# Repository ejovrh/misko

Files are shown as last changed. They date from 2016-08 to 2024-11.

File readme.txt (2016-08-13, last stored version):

miško - the self sufficient gps tracker

1. ABOUT
	TODO
	Once upon a time, the need was to be able to geotag pictures I take with my camera while enjoying outdor activities.
	I order to satisfy this need I purchased the so-popular GPS recievers which run on a single AA battery (and have a bluetooth 
	transmitter) and a bluetooth module that attaches to the camera.
	This has proven to be futile because of battery runtime, storage capacity and so on.
	
	The original GPS tracker started its life as a (curiosity) kit from adafruit out of the need to have a 
		GPS tracker for my outdoor adventures which meets the following criteria:
			- does not run on AA batteries
			- has a sufficiently long standalone runtime
			- provides logging funcionality 
			- provides a bluetooth interface so that I can geotag pictures I take
			- can be charged by various means
			
		There are professional GPS devices which can (partly) do the job but they do cost a bit more than petty cash 
		and im not that rich.
		
		In my Searches on the Internet I did not find a product which has all the above features implemented; i did find, however, 
		a kit which provides logging of GPS data to a SD card.
		
		Now, GPS modules -usually- use the NMEA protocol; NMEA -usually- utilizes RS232 as a transport [TTL is another choice].
		RS232 is used by the kit's logic to parse incoming data and (RS232) can be easily fed into a bluetooth module.
		The camera has a bluetooth module - it is naturaly to experiment and see if this kit can be tailored to my needs.
		
		This repository attepts two things:
			- document the efforts of producing a suitable GPS tracker (its my university thesis, after all....)
			- produce a GPS tracker which has the following main features:
				- records GPS data and writes it to storage media (after vacations, google earth and the visited route are a nice thing to have)
				- provides NMEA sentences to the camera via bluetooth to geotag pictues
				- has sufficiently long runtime
				- comes in a waterproof box, is to some extent shockproof, dustproof and can handle some abuse
				- can be supplied with electricity on the road (by means of bicycle dynamo, solar cells, mains outlet)
				- can, if need be, charge my mobile phone
				- has certain functionalities user-configurable via buttons
				- displays certain tokens of inromation via LCD
				
				bonus features:
					- uploads the route at definable intervals to some server via GSM ( Big Mother is watching... )
					- log other interesting data to storage
					- get rid of the awful Arduino IDE and use a real one - AVR studio, for example
					
		That's the rough story of it...

2. SOFTWARE USED
	Arduino IED - an open source IDE for the atmel chips
		https://www.arduino.cc/en/Main/Donate
		note: in windows 7 you may need to manually opdate drivers 
		reason: it may be that the ATmega2560 board is not recognized with the stock OS driver
				the appropriate driver is located in the arduino installation
				go to device manager, find the faulty USB device, manually update driver from the arduino install path
		
	Arduino core libraries
		https://www.arduino.cc/en/Reference/Libraries
		SoftwareSerial, SD, EEPROM for interfacing various devices offered by the atmega2560

	Fritzing - an open source entry-level PCB design tool
		http://fritzing.org/download/?donation=0
		
	MS Visio 
		used for some diagrams

	AutoCAD 
		used for enclosure diagrams, stl files for 3D printing
		
	tortoise git
		https://tortoisegit.org/
		a frontend for GIT, utilizing the github repository
		"git for windows" is needed as the backend for communication/functionality of hte github repository
		
	git for windows
		https://git-for-windows.github.io/
		the backed for git-for-windows
			
	u8glib
		https://github.com/olikraus/u8glib
		a display driver library for all kinds of displays
		
	m2tklib
		https://github.com/olikraus/m2tklib
		an graphics library for all kinds of display devices

3. FILES / FOLDERS
	datasheets: contains datasheets, user guides for components
	misko-prototype: prototype firmware code which provides GPS tracker functionality
	battery holder.dwg: AutoCAD drawing of the battery holder
	LiIon battery.dwg: crude AutoCAD model of one battery, contains lateral dimensions
	prototype gps tracker - high level diagram.vsd: MSVisio diagram showing a high level overview of the hardware setup
	readme.txt: this file
	universal hardcase 50.dwg: crude AutoCAD drawing of the enclosure 
	
4. DEVICES
	4.1 misko-prototype
		The original hardware, in kit-form, lived its life in an Iphone3 box and has seen parts of the world on my bicycle.
		It worked well for its humble beginnings, but not well enough.
		Now it lives its life on a piece of cardboard, connected to breadboards, does not leave the home and serves as a 
		development instance.
		
		The role of this environment is development (hardware and software).
		
	4.2 misko-qa
		TODO
		The QA hardware/instance will be based on the prototype's schematics - PCB's tailored to fit into the enclosure and to 
		support features listed.
		Provided the PCB's are good (free of hardware bugs), it will serve as a software (and partially hardware) QA instance for the 
		jump of changes from development to production hardware.
	
	4.2 misko-prod
		TODO
		The production hardware/instance will be used in a live environment (real travels with rain and wind and everything).
		
		Changes on this environment will go through a controlled change cycle - first dev, then QA, then prod.
		
		Developers who know me from my work environment are entitled to my opinion and may now laugh as much as they want.
		
5. HARDWARE USED

	- Arduino Mega2560
		http://hr.rsdelivers.com/product/arduino/a000067/arduino-mega/7154084.aspx

	- Analog Devices TMP36FSZ Temperature Sensor 8-Pin SOIC
		http://hr.rsdelivers.com/product/analog-devices/tmp36fsz/analog-devices-tmp36fsz-temperature-sensor-8-pin-soic-40-125-c/0412973.aspx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
	
	- International Rectifier IRLZ44NSTRLPBF N-channel MOSFET Transistor, 47 A, 55 V, 3-Pin D2PAK
		http://hr.rsdelivers.com/product/international-rectifier/irlz44nstrlpbf/international-rectifier-irlz44nstrlpbf-n-channel-mosfet-transistor-47-a-55-v-3-pin-d2pak/8303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
		
	- Texas Instruments SN74AHC14D, Hex Schmitt Trigger Inverter, 8mA, 2 → 5.5 V, 14-Pin SOIC

		http://hr.rsdelivers.com/product/texas-instruments/sn74ahc14d/texas-instruments-sn74ahc14d-hex-schmitt-trigger-inverter-8ma-2-55-v-14-pin-soic/0526616.aspx
		
	- Atmel 2560
	
		http://hr.rsdelivers.com/catalogue/search.aspx?query=atmega2560&Family=9511#PI-1|viewtype-0|A-236854|
	
	- Microchip 23K256-I/SN SRAM Memory, 256kbit, 2.7 → 3.6 V, 25ns 8-Pin SOIC
	
		http://hr.rsdelivers.com/product/microchip/23k256-i-sn/microchip-23k256-i-sn-sram-memory-256kbit-27-36-v-25ns-8-pin-soic/6668148.aspx
		
	-

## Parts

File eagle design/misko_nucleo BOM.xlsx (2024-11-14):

Qty | Value | Device | Package | Parts | Description
1 | 1.5F 4F | EECS5R5H155 MAL219691104E3 | TH | GPS:SC:C24 | supercap 1.5F or 4F | 504-HS0814-3R8106-R 594-MAL219691104E3 | https://eu.mouser.com/ProductDetail/504-HS0814-3R8106-R https://eu.mouser.com/ProductDetail/594-MAL219691104E3
1 | 100k | R-EU_R0402 | R0402 | GPS:SV:R18 | RESISTOR, European symbol | 667-ERA-2AEB104X | https://eu.mouser.com/ProductDetail/Panasonic/ERA-2AEB104X?qs=YFwoyZoVY0jijibKYIWHHg%3D%3D
1 | 1u / 16V | C-EUC0402 | C0402 | GPS:G:C2 | CAPACITOR, European symbol | 963-TMK105BJ105MV-F | https://hr.mouser.com/ProductDetail/963-TMK105BJ105MV-F
1 | 33R | R-EU_R1206 | R1206 | GPS:SC:R1 | RESISTOR, European symbol | 754-HRG3216Q33R0DT1 | https://eu.mouser.com/ProductDetail/Susumu/HRG3216Q-33R0-D-T1?qs=Pccw3SRxl2QVimWmCTvNQQ%3D%3D
1 | 47309-2651 | MICROSD_SPI_MODE | MICRO_SD_CONNECTOR | IC1101 | MOLEX - 49225-0821 - CONNECTEUR MICRO SD PUSH/PUSH REVFabricant: MOLEXCode commande Farnell: 1366700Référence fabricant: 49225-0821 | 538-47309-2651 | https://eu.mouser.com/ProductDetail/Molex/47309-2651?qs=%252Bi0aAQIdfgCnu2Vhp4wRvw%3D%3D
1 | 47nF / 10V | C-EUC0402 | C0402 | C401 | CAPACITOR, European symbol | 81-GRT155R71H473KE1D | https://eu.mouser.com/ProductDetail/81-GRT155R71H473KE1D
1 | 55R | R-EU_R0402 | R0402 | R1701 | RESISTOR, European symbol | 667-ERA-2AEB54R9X | https://eu.mouser.com/ProductDetail/Panasonic/ERA-2AEB54R9X?qs=nuXzIS8loXFivPgOLhNE3A%3D%3D
1 | 65R | R-EU_R0402 | R0402 | R1702 | RESISTOR, European symbol | 667-ERA-2AEB64R9X | https://eu.mouser.com/ProductDetail/Panasonic/ERA-2AEB64R9X?qs=nuXzIS8loXHLmutffSowkg%3D%3D
1 | 74HCT1G32GW | 74HCT1G32GW-DC | SOT353/5 | IC1302 | Two Input OR gate | 771-HCT1G32GW125 | https://eu.mouser.com/ProductDetail/Nexperia/74HCT1G32GW125?qs=P62ublwmbi9uVFb7WoNXSA%3D%3D
1 | ADXL345 | ADXL345 | LGA14 | IC1301 | 3-Axis, ±2 g/±4 g/±8 g/±16 g Digital Accelerometer | 584-ADXL345BCCZ | https://eu.mouser.com/ProductDetail/584-ADXL345BCCZ
1 | FM25W256 | FM25W256-SOIC | SOIC08 | IC1201 | FeRAM Module | 877-FM25W256-GTR | https://eu.mouser.com/ProductDetail/Infineon-Technologies/FM25W256-GTR?qs=pA5MXup5wxGoDW6i2AFyWw%3D%3D
1 | LTC4425EDD#PBF | LTC4425DFN-12 | DFN-12 | GPS:SC:IC2 | The ISL85003 and ISL85003A are synchronous buck regulators with integrated high-side and low-side FET’s. The regulator can operate from an input voltage range of 4.5V to 18V while delivering a very efficient continuous 3A current. | 584-LTC4425EDD#PBF | https://eu.mouser.com/ProductDetail/584-LTC4425EDD%23PBF
1 | ORG1510-MK4 | ORG1510-MK4 | SMD | GPS:G:IC1
1 | TCAN334 | CAN33X | SOT23-8 | IC401 |  | 595-TCAN334GDCNT | https://eu.mouser.com/ProductDetail/595-TCAN334GDCNT
1 | TPS3808G33DBVT | TPS3808WSON6 | WSON-6 | GPS:SV:IC2 | Low Quiescent Current, Programmable-Delay Supervisory Circuit | 595-TPS3808G33DRVT | https://eu.mouser.com/ProductDetail/595-TPS3808G33DRVT
1 | WP710A10LZGCK | LEDSQR2X5 | LED2X5 | LED1703 | LED | 604-WP710A10LZGCK | https://eu.mouser.com/ProductDetail/604-WP710A10LZGCK
1 | WP710A10SEC | LEDSQR2X5 | LED2X5 | LED1701 | LED | 604-WP710A10SEC | https://eu.mouser.com/ProductDetail/604-WP710A10SEC
1 | WP710A10SECK/J3 | LEDSQR2X5 | LED2X5 | LED1704 | LED | 604-WP710A10SECKJ3 | https://eu.mouser.com/ProductDetail/604-WP710A10SECKJ3
1 | misko | NUCLEO-H503RB-B02 | NUCLEO-H503RB-B02 | BRD1 | Check availability | 511-NUCLEO-H503RB | https://eu.mouser.com/ProductDetail/STMicroelectronics/NUCLEO-H503RB?qs=Jm2GQyTW%2Fbg7Js7%2FR9xxmw%3D%3D
2 | 100u / 16V | C-EUC1210 | C1210 | GPS:SC:C1, GPS:SC:C34 | CAPACITOR, European symbol | 581-1210YD107MAT2A | https://eu.mouser.com/ProductDetail/KYOCERA-AVX/1210YD107MAT2A?qs=dTuOkNN7mNJArH0RUYK6ig%3D%3D
2 | 10k | R-EU_R0402 | R0402 | GPS:SC:R2, GPS:SC:R14 | RESISTOR, European symbol | 667-ERA-2AEB103X | https://hr.mouser.com/ProductDetail/667-ERA-2AEB103X
2 | 150k | R-EU_R0402 | R0402 | GPS:SC:R40, GPS:SC:R41 | RESISTOR, European symbol | 603-RT0402FRE07150KL | https://hr.mouser.com/ProductDetail/603-RT0402FRE07150KL
2 | 33p / 16V | C-EUC0402 | C0402 | GPS:G:C22, GPS:G:C31 | CAPACITOR, European symbol | 80-C0402C330J4RAUTO | https://eu.mouser.com/ProductDetail/KEMET/C0402C330J4RACAUTO?qs=yQ9FZw9SO3y3aZ9BD6Y8Rw%3D%3D
2 | 60 | R-EU_R0805 | R0805 | R401, R405 | RESISTOR, European symbol | 667-ERA-6AEB60R4V | https://eu.mouser.com/ProductDetail/667-ERA-6AEB60R4V
2 | TL3305CF160QG | TL3305-844809 | SMD | SW1401, SW1402 |  | 612-TL3305CF160QG | https://eu.mouser.com/ProductDetail/?qs=UrFqKgNWc7QzvF9YzOUMwg%3D%3D
3 | 33R | R-EU_R0402 | R0402 | GPS:G:R1, GPS:G:R2, R1703 | RESISTOR, European symbol | 279-CPF0402B33RE1 | https://eu.mouser.com/ProductDetail/TE-Connectivity-Holsworthy/CPF0402B33RE1?qs=iJVBkmKXgrn7rsFDnZJSMA%3D%3D
4 | SQ2310ES-T1_BE3 | BSS123 | SOT23 | GPS:SC:Q4, Q1701, Q1702, Q1703 | N-CHANNEL MOS FET | 78-SQ2310ES-T1_BE3 | https://eu.mouser.com/ProductDetail/Vishay-Siliconix/SQ2310ES-T1_BE3?qs=TiOZkKH1s2S1D6d8keGc4Q%3D%3D
8 | 0.1u / 16V | C-EUC0402 | C0402 | C405, C1131, C1201, C1304, GPS:G:C1, GPS:SC:C38, GPS:SV:C1, GPS:SV:C2 | CAPACITOR, European symbol | 80-C0402C104J4RECLR | https://hr.mouser.com/ProductDetail/80-C0402C104J4RECLR

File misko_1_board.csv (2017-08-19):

Part | Value | Device | Package | Description | DESCRIPTION | MF | MPN | OC_FARNELL | OC_NEWARK | PACKAGE | SUPPLIER | TP_SIGNAL_NAME
C1 | 18pF | C-EUC0805 | C0805 | CAPACITOR, European symbol
C2 | 1µF | C-EUC0805 | C0805 | CAPACITOR, European symbol
C3 | 0.1µF | C-EUC0805 | C0805 | CAPACITOR, European symbol
C4 | 0.1µF | C-EUC0805 | C0805 | CAPACITOR, European symbol
C5 | 10µF | C-EUC0805 | C0805 | CAPACITOR, European symbol
C6 | 4.7µF | C-EUC0805 | C0805 | CAPACITOR, European symbol
C7 | 18pF | C-EUC0805 | C0805 | CAPACITOR, European symbol
C8 | 15pF | C-EUC0805 | C0805 | CAPACITOR, European symbol
C9 | 1µF | C-EUC0805 | C0805 | CAPACITOR, European symbol
C10 | 1µF | C-EUC0805 | C0805 | CAPACITOR, European symbol
C11 | 10µF | C-EUC0805 | C0805 | CAPACITOR, European symbol
C12 | 15pF | C-EUC0805 | C0805 | CAPACITOR, European symbol
C13 | 0.1µF | C-EUC0805 | C0805 | CAPACITOR, European symbol
C14 | 1µF | C-EUC0805 | C0805 | CAPACITOR, European symbol
C15 | 1µF | C-EUC0805 | C0805 | CAPACITOR, European symbol
C16 | 10µF | C-EUC0805 | C0805 | CAPACITOR, European symbol
C17 | 2.2µF / 25V | C-EUC0805 | C0805 | CAPACITOR, European symbol
C18 | 1nF | C-EUC0805 | C0805 | CAPACITOR, European symbol
C19 | 0.1µF | C-EUC0805 | C0805 | CAPACITOR, European symbol
C20 | 0.1µF | C-EUC0805 | C0805 | CAPACITOR, European symbol
C21 | 0.1µF | C-EUC0805 | C0805 | CAPACITOR, European symbol
C22 | 10µF | C-EUC0805 | C0805 | CAPACITOR, European symbol
C23 | 10µF | C-EUC0805 | C0805 | CAPACITOR, European symbol
C24 | 10pF | C-EUC0805 | C0805 | CAPACITOR, European symbol
C25 | 1.5F | EECS5R5H155 | TH
C26 | 33pF | C-EUC0805 | C0805 | CAPACITOR, European symbol
C27 | 1000µF | CPOL-EUE5-10.5 | E5-10,5 | POLARIZED CAPACITOR, European symbol
C28 | 10µF | C-EUC0805 | C0805 | CAPACITOR, European symbol
C29 | 10µF | C-EUC0805 | C0805 | CAPACITOR, European symbol
C30 | 1000µF | CPOL-EUE5-10.5 | E5-10,5 | POLARIZED CAPACITOR, European symbol
C31 | 1000µF | CPOL-EUE5-10.5 | E5-10,5 | POLARIZED CAPACITOR, European symbol
C32 | 0.1µF | C-EUC0805 | C0805 | CAPACITOR, European symbol
C33 | 10µF | C-EUC0805 | C0805 | CAPACITOR, European symbol
C34 | 10µF | C-EUC0805 | C0805 | CAPACITOR, European symbol
C35 | 1000µF | CPOL-EUE5-10.5 | E5-10,5 | POLARIZED CAPACITOR, European symbol
C36 | 0.1µF | C-EUC0805 | C0805 | CAPACITOR, European symbol
C37 | 10µF | C-EUC0805 | C0805 | CAPACITOR, European symbol
C38 | 1000µF | CPOL-EUE5-10.5 | E5-10,5 | POLARIZED CAPACITOR, European symbol
C39 | 100µF | C-EUC0805 | C0805 | CAPACITOR, European symbol
C40 | 100µF | C-EUC0805 | C0805 | CAPACITOR, European symbol
C41 | 0.1µF | C-EUC0805 | C0805 | CAPACITOR, European symbol
C42 | 0.1µF | C-EUC0805 | C0805 | CAPACITOR, European symbol
C43 | 0.1µF | C-EUC0805 | C0805 | CAPACITOR, European symbol
CONN1 | JTAG | JTAG-1.27-10-PIN-HEADER | TH-JTAG
CONN2 | I2C | JP4E | JP4 | JUMPER
CONN3 | LiPo Battery | JST_2PIN-THM-RA | JST-PH-2-THM-RA | JST 2-Pin Connectors of various flavors
CONN4 | USB mini B | MX-67503-1230 | SMT
CONN5 | U.FL-R-SMT 1 | ANTENNASMD | SMD | Antenna
D1 | 1N4148 | 1N4148 | D0805 | DIODE
D2 | BAT60AE6327 | BAT60J | SOD323_ST | Schottky barrier diode
D3 | MMSZ5231B-DIO | DIODE-SOD123 | SOD123 | DIODE
IC1 | ATMEGA1281-16AU | ATMEGA1281-16AU | QFP80P1600X1600X120-64N | Microcontroller | Microcontroller |  | ATMEGA1281-16AU | 1455092 | 58M3721 | QFP-64 | ATMEL
IC2 | MC1525TT | MC1525TT | SOT23 | 2.5V and 4.096V Voltage References |  |  |  | unknown | unknown
IC3 | TMP36GRTZ | TMP36GRTZ-REEL7 | SOT95P280X145-5N | Low Voltage Temperature Sensors |  |  | TMP36GRTZ-REEL7 | 1661084 | 96K2116 | SOT23-5 | Analog Devices
IC4 | TPS63031 | TPS63001DRCR | SMT
IC5 | MCP73871-2AAI/ML | MCP73871-2AAI/ML | QFN50P400X400X100-21N | IC, BATTERY CHARGER, 1A |  |  | MCP73871-2AAI/ML | 1642487 | 54M4955 | QFN-20 | Microchip
IC6 | MAX6818 | MAX6818 | TSSOP20
IC7 | FT230XS | FT230XS | SSOP16 | USB to BASIC UART IC
IC8 | SN74LVC1G3157DBVR - BT switch | SN74LVC1G3157DBVR | SOT95P280X145-6N | SINGLE-POLE, DOUBLE-THROW ANALOG SWITCH |  |  | SN74LVC1G3157DBVR | 1470910 | 32H6364 | SOT-23-6 | Texas Instruments
IC9 | SN74LVC1G3157DBVR - GPS switch | SN74LVC1G3157DBVR | SOT95P280X145-6N | SINGLE-POLE, DOUBLE-THROW ANALOG SWITCH |  |  | SN74LVC1G3157DBVR | 1470910 | 32H6364 | SOT-23-6 | Texas Instruments
IC10 | ORG1510-MK4 | ORG1510-MK4 | PACKAGE
IC11 | TPS3808G33DBVT | TPS3808G33DBVT | SOT95P280X145-6N | Low Quiescent Current, Programmable-Delay Supervisory Circuit |  |  | TPS3808G33DBVT | 1755534 | 21J9211 | SOT-23-6 | Texas Instruments
IC12 | LTC4425 | LTC4425 | MSOP | The ISL85003 and ISL85003A are synchronous buck regulators with integrated high-side and low-side FET’s. The regulator can operate from an input voltage range of 4.5V to 18V while delivering a very efficient continuous 3A current.
IC13 | RN4678_BT_MODULE | RN4678_BT_MODULE | SMT
IC14 | ADXL345 | ADXL345 | LGA14 | 3-Axis, ±2 g/±4 g/±8 g/±16 g Digital Accelerometer
IC15 | 74HCT1G32 | 74HCT1G32GW-DC | SOT353/5 | Two Input OR gate
IC16 | FM25W256-SOIC | FM25W256-SOIC | SOIC08 | FeRAM Module |  |  |  | unknown | unknown
IC17 | MICROSD_SPI_MODE | MICROSD_SPI_MODE | MICRO_SD_CONNECTOR | MOLEX - 49225-0821 - CONNECTEUR MICRO SD PUSH/PUSH REVFabricant: MOLEXCode commande Farnell: 1366700Référence fabricant: 49225-0821
IC18 | FH12-30S-0.5SH | FH12-30S-0.5SH | FH12-30S-0.5SH | 0.5mm Pitch Connectors For FPC/FFC |  |  | FH12-30S-0.5SH(55) | 1324555 | 34M6176
IC19 | DS1394U-33+ | DS1394U-33+ | 10UMAX
IC20 | ATWINC1500-MR210PB | ATWINC1500-MR210PB | SMT
IC21 | 115Q-BCA0 | 115Q-BCA0 | 115Q-BCA0
IC22 | SIM800 | SIM800 | SIM800C
L1 | 33µH | L-US | L0805 | INDUCTOR, American symbol
L2 | DJNR3015-1R5 | DJNR3015-1R5 | FFF
L3 | DJNR6045-100-S | DJNR6045-100-S | DJNR6045-100-S | Shielded Power Inductors
LED1 | yellow | LEDCHIPLED_1206 | CHIPLED_1206 | LED
LED2 | yellow | LEDCHIPLED_1206 | CHIPLED_1206 | LED
LED3 | green | LEDSQR2X5 | LED2X5 | LED
LED4 | red | LEDSQR2X5 | LED2X5 | LED
Q1 | ABM3B | ABM3B | SMT
Q2 | LFXTAL016178R | LFXTAL016178R | SMD
R1 | 47k | R-EU_R0805 | R0805 | RESISTOR, European symbol
R2 | 150k | R-EU_R0805 | R0805 | RESISTOR, European symbol
R3 | 4k7 | R-EU_R0805 | R0805 | RESISTOR, European symbol
R4 | 3k3 | R-EU_R0805 | R0805 | RESISTOR, European symbol
R5 | 3k3 | R-EU_R0805 | R0805 | RESISTOR, European symbol
R6 | 27 | R-EU_R0805 | R0805 | RESISTOR, European symbol
R7 | 150k | R-EU_R0805 | R0805 | RESISTOR, European symbol
R8 | 150k | R-EU_R0805 | R0805 | RESISTOR, European symbol
R9 | 10k | R-EU_R0805 | R0805 | RESISTOR, European symbol
R10 | 27 | R-EU_R0805 | R0805 | RESISTOR, European symbol
R11 | 10k | R-EU_R0805 | R0805 | RESISTOR, European symbol
R12 | 100k | R-EU_R0805 | R0805 | RESISTOR, European symbol
R13 | 270k | R-EU_R0805 | R0805 | RESISTOR, European symbol
R14 | 1k | R-EU_R0805 | R0805 | RESISTOR, European symbol
R15 | 1k | R-EU_R0805 | R0805 | RESISTOR, European symbol
R16 | 47k | R-EU_R0805 | R0805 | RESISTOR, European symbol
R17 | 1k | R-EU_R0805 | R0805 | RESISTOR, European symbol
R18 | 1k | R-EU_R0805 | R0805 | RESISTOR, European symbol
R19 | 10k | R-EU_R0805 | R0805 | RESISTOR, European symbol
R20 | 47k | R-EU_R0805 | R0805 | RESISTOR, European symbol
R21 | 1M | R-EU_R0805 | R0805 | RESISTOR, European symbol
R22 | 1k | R-EU_R0805 | R0805 | RESISTOR, European symbol
R25 | 47k | R-EU_R0805 | R0805 | RESISTOR, European symbol
R26 | 390k | R-EU_R0805 | R0805 | RESISTOR, European symbol
R27 | 10k | R-EU_R0805 | R0805 | RESISTOR, European symbol
R28 | 10k | R-EU_R0805 | R0805 | RESISTOR, European symbol
R29 | 1M | R-EU_R0805 | R0805 | RESISTOR, European symbol
R30 | 1k | R-EU_R0805 | R0805 | RESISTOR, European symbol
R31 | 47k | R-EU_R0805 | R0805 | RESISTOR, European symbol
R32 | 10k | R-EU_R0805 | R0805 | RESISTOR, European symbol
R33 | 1k | R-EU_R0805 | R0805 | RESISTOR, European symbol
R34 | 1k | R-EU_R0805 | R0805 | RESISTOR, European symbol
R35 | 1k | R-EU_R0805 | R0805 | RESISTOR, European symbol
R36 | 10k | R-EU_R0805 | R0805 | RESISTOR, European symbol
R37 | 100k | R-EU_R0805 | R0805 | RESISTOR, European symbol
R38 | 1k | R-EU_R0805 | R0805 | RESISTOR, European symbol
R39 | 270k | R-EU_R0805 | R0805 | RESISTOR, European symbol
R40 | NTC 10k | R-EU_0204/5 | 0204/5 | RESISTOR, European symbol
R41 | 10k | R-EU_R0805 | R0805 | RESISTOR, European symbol
R42 | 10k | R-EU_R0805 | R0805 | RESISTOR, European symbol
R43 | 10k | R-EU_R0805 | R0805 | RESISTOR, European symbol
R44 | 150k | R-EU_R0805 | R0805 | RESISTOR, European symbol
R45 | 150k | R-EU_R0805 | R0805 | RESISTOR, European symbol
R46 | 150k | R-EU_R0805 | R0805 | RESISTOR, European symbol
R47 | 150k | R-EU_R0805 | R0805 | RESISTOR, European symbol
SJ1 | WiFi RST | SJW | SJW | SMD solder JUMPER
SJ2 | GPIO6 | SJW | SJW | SMD solder JUMPER
SJ3 | RESET | SJW | SJW | SMD solder JUMPER
SW1 | RESET | 430152050836 | 430152050836 | 6x6 mm SMD WS-TASV
SW2 | POWER SWITCH | SWS001 | SMS-001 | SMD Dip Switch 1 pol.
SW3 | MICROJOYSTICK | MICROJOYSTICK | MICROJOYSTICK
SW4 | PB6156RSL | PB6156RSL | TH
SW5 | PB6156RSL | PB6156RSL | TH
T1 | BSS84 | BSS84 | SOT23 | P-CHANNEL MOS FET
TP1 | GND | TPPAD1-17Y | P1-17Y | Test pad
TP2 | GND | TPPAD1-17Y | P1-17Y | Test pad
TP3 | GND | TPPAD1-17Y | P1-17Y | Test pad
TP4 | VCC | PTR1TP14R | TP14R | TEST PIN
TP5 | VLiIon Regulated | PTR1TP14R | TP14R | TEST PIN
TP6 | VGPS | PTR1TP14R | TP14R | TEST PIN
TP7 | Analogue Switch CRTL Pin | PTR1TP14R | TP14R | TEST PIN
TP8 | GPS Power CTRL Pin | PTR1B1,27 | B1,27 | TEST PIN
TP9 | SIM800 Power CTRL Pin | PTR1B1,27 | B1,27 | TEST PIN
TP10 | Bluetooth Wakeup Pin | PTR1TP14R | TP14R | TEST PIN
TP11 | Bluetooth Wakeup Pin | PTR1TP14R | TP14R | TEST PIN

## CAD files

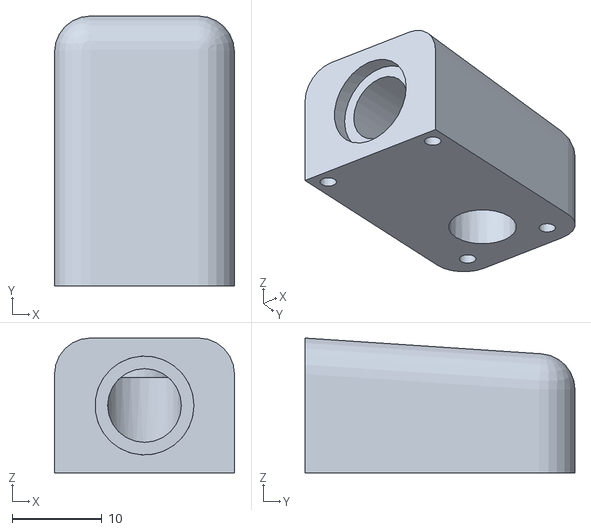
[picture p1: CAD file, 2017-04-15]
universal hardcase 75 - external.stl
20.0 x 30.0 x 15.0

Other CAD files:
universal hardcase 75.dwg
universal hardcase 75 - external.dwg

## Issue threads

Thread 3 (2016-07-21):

document existing prototype

ejovrh, 2016-07-21:
draw up visio diagrams (or similar) showing a block-diagram like overview of components and features so that sbojanic can understand the apparatus

ejovrh, 2016-07-23:
crude block-level diagram with basic data flows and voltages in visio is done

ejovrh, 2016-08-20:
is closed via a block level diagram in splan7

Closed 2016-08-20.

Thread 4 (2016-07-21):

load up the prototype code into git

ejovrh, 2016-07-21:
upload the prototype code, comment it, list open issues and bugs

ejovrh, 2016-07-23:
done, the whole tree is in github, code is compiling, programming works, board functions "as intended"

Closed 2016-07-23.

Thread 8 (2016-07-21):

draw rough battery autocad model

ejovrh, 2016-07-21:
draw the battery model so that a holder for them can be 3dprinted and inserted into the enclosure

Closed 2016-07-21.

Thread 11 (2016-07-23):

document prototype code

ejovrh, 2016-07-23:

ejovrh, 2016-08-12:
the original prototype code is by now so much changed that it doesn't resemble its original form anymore.
this issue can be closed since most components are documented in the code.

Closed 2016-08-12.

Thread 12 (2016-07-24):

fix bluetooth module power

ejovrh, 2016-07-24:
atm it is supplied via 100% PWM duty cycle on pin 9

implement a mosfet via which an analog? port shall trigger the gate

ejovrh, 2016-07-25:
fixed.
bluetooth module power is not controlled via a mosfet, the gate is controlled by pin 53 - bluetooth_mosfet_gate_pin

Closed 2016-07-25.

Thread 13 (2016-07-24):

bluetooth power - implement switchable power by key press, turns off after some time

ejovrh, 2016-07-24:
implement button press for power toggle.
e.g.:
0-1s - power for 20s
2-3s - power for 40s

double click: toggle power on
double click again: toggle power off

perhaps time setting could be implemented by a default and adjustable by LCD menu item

ejovrh, 2016-07-31:
implemented
the method of operation is not a double click but button hold.

if the BT button is held for 500ms or longer, it will turn the BT device on (or off).
state is kept via flags

the button handling logic is improved so that on press only one event is registered (same goes for release).
the timed power off will not kick in if the device power is toggled via "500ms or longer" button hold.

Closed 2016-07-31.

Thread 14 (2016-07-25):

check pins 50-52 for correct operation

ejovrh, 2016-07-25:
test case:
connect e.g. lcd mosfet gate to 50, put on high, upload, check power status of lcd, retest with low state
power state was not consistent

ejovrh, 2016-07-26:
it pays to read the documentation. said pins are reserved for SPI...

Closed 2016-07-26.

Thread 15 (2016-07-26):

make 5-button keypad

ejovrh, 2016-07-26:
- 5 buttons: left, right, up, down, bluetooth toggle
- use hardware debouncing (I'm too lazy to code it) [schmitt trigger]
- in software, digitalRead() shall be enough to determine pin states
- do the math for it: calculate RC circuit for thesis, perhaps (in parallel to math) record it on a oscilloscope [problem is time resolution!!] to see actual results

one good read is https://www.ikalogic.com/de-bouncing-circuits/
another one is http://www.eng.utah.edu/~cs5780/debouncing.pdf

ejovrh, 2016-07-30:
hardware is made, tested and seems to work.
missing is the math and a osci picture showing it

ejovrh, 2016-08-22:
the osci-analysis is not needed

Closed 2016-08-22.

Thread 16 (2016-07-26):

rewrite SD card logging

ejovrh, 2016-07-26:
the current approach uses FAT and writes with 1Hz frequency to the card.
data written is about 2X80 characters (with current NEMA sentence selection) - the card is literally burned since there are lots of writes to the same blocks.
this leads to heavy and unrecoverable FS corruption and the card can eventually be thrown away.

implement:
- SD card utilization which will mitigate excessive writing to the same blocks
- a buffer which will hold NMEA sentences in flash memory and e.g. once in 5 minutes flush its contents to the SD card
- devise a way to read out SD card data without the need to physically remove it from the device
- enable card space utilization statistics, display them on a LCD

Closed 2016-08-27.

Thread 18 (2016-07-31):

rewrite button handlers

ejovrh, 2016-07-31:
their current state is a disgrace; copy and paste code.

ejovrh, 2016-08-20:
left, right, up and down were removed since these are now handled by the M2tk library.
the bluetooth button was rewritten to make it less(more?) complicated and more(less?) clear.
[ at least it has comments... ]

Closed 2016-08-20.

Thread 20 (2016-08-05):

OLED <-> SD issue

ejovrh, 2016-08-05:
the SD card (SPI) init seems to interfere with the OLED on I2C.
fix the issue either with utilizing a different OLED (one with hardware SPI) or otherwise.

ejovrh, 2016-08-13:
resolved.
the culprits were:
- SD.begin() interfered with SPI OLED setup, disabling SD-begin() enabled the OLED to work
- wrong wiring on at least one occasion of tests with HW SPI wiring
- switching to card.init() enabled card initialization and OLED operation at the same time.

Closed 2016-08-13.

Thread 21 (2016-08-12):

improve menu

ejovrh, 2016-08-12:
at the moment the menu displays the basic data needed for the tracker to function.
there are a few missing items (battery status, temperature, lineup of menu elements).
most of them are hardware-independent and can be implemented at a later date.

Closed 2016-08-28.

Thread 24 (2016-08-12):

implement TP36

ejovrh, 2016-08-12:
a temperature sensor shall be implemented and the temperature shall be displayed.
parse frequency shall be a sane ammount of time - e.g. once in 5 minutes

ejovrh, 2016-08-12:
is implemented and tested.
it seems to work well enough, however changes may be made based upon global variables, timer functions and similar things.

ejovrh, 2016-08-13:
the measured voltage fluctuates a lot.
implement an average measurement

ejovrh, 2016-08-21:
implemented an average measurement over configurable iterations.
iterative runs are executed via a primitive scheduler which runs about once per seconds.

Closed 2016-08-21.

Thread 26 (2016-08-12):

implemend ADXL345 accelerometer

ejovrh, 2016-08-12:
the accelerometer shall put the device in a proper sleep state in order to preserve power when no movement is detected.
for this the ADXL345 can trigger interrupt events which the micro-controller has to be able to respond to (go to sleep and wake up after wards).

ejovrh, 2016-08-15:
basic interrupt events are now registered. sleep and power saving is still todo

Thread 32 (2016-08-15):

adxl345_readByte(DEVID) returns 0 on 1st call, subsequent calls are ok

ejovrh, 2016-08-15:
weird issue: the 1st read returns 0, subsequent reads return proper values

ejovrh, 2016-08-22:
this seems to be a wiring issue on the breadboad.
SPI is running at MHz speeds and i have bad contacts, the breadboard - unpredictable sources of capacitance, inductance and resistance.

Closed 2016-08-22.

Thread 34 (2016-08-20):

implement bt power status

ejovrh, 2016-08-20:
bt constant power on/auto /constant off shall be implemented.

ejovrh, 2016-08-20:
implemented via M2_COMBOFN and a nasty bluetooth button handler.
it event works!

Closed 2016-08-20.

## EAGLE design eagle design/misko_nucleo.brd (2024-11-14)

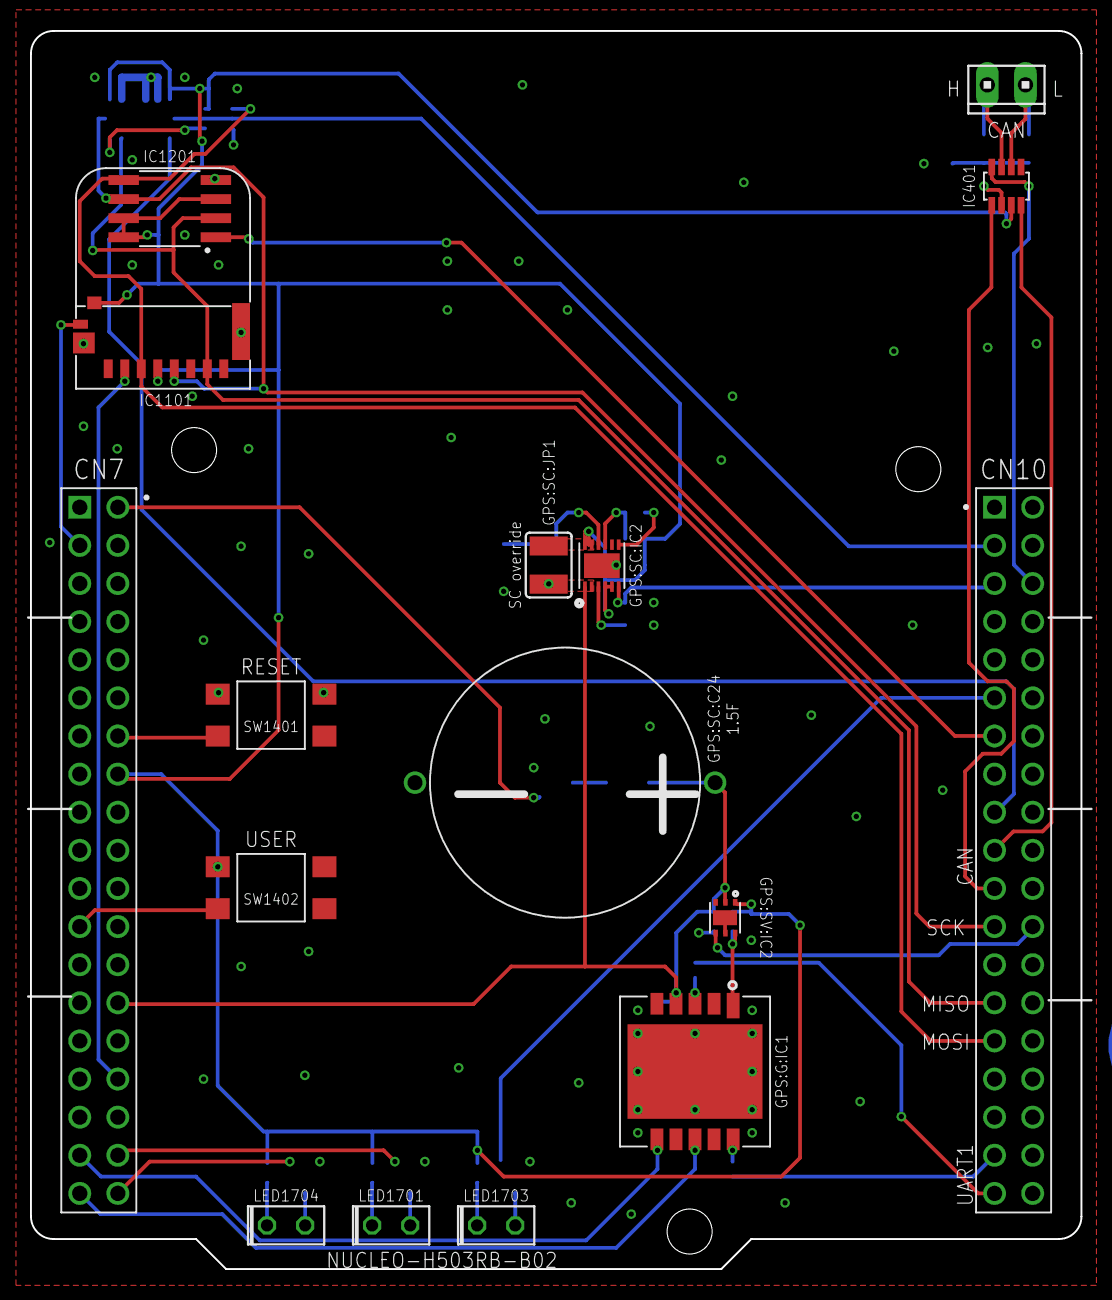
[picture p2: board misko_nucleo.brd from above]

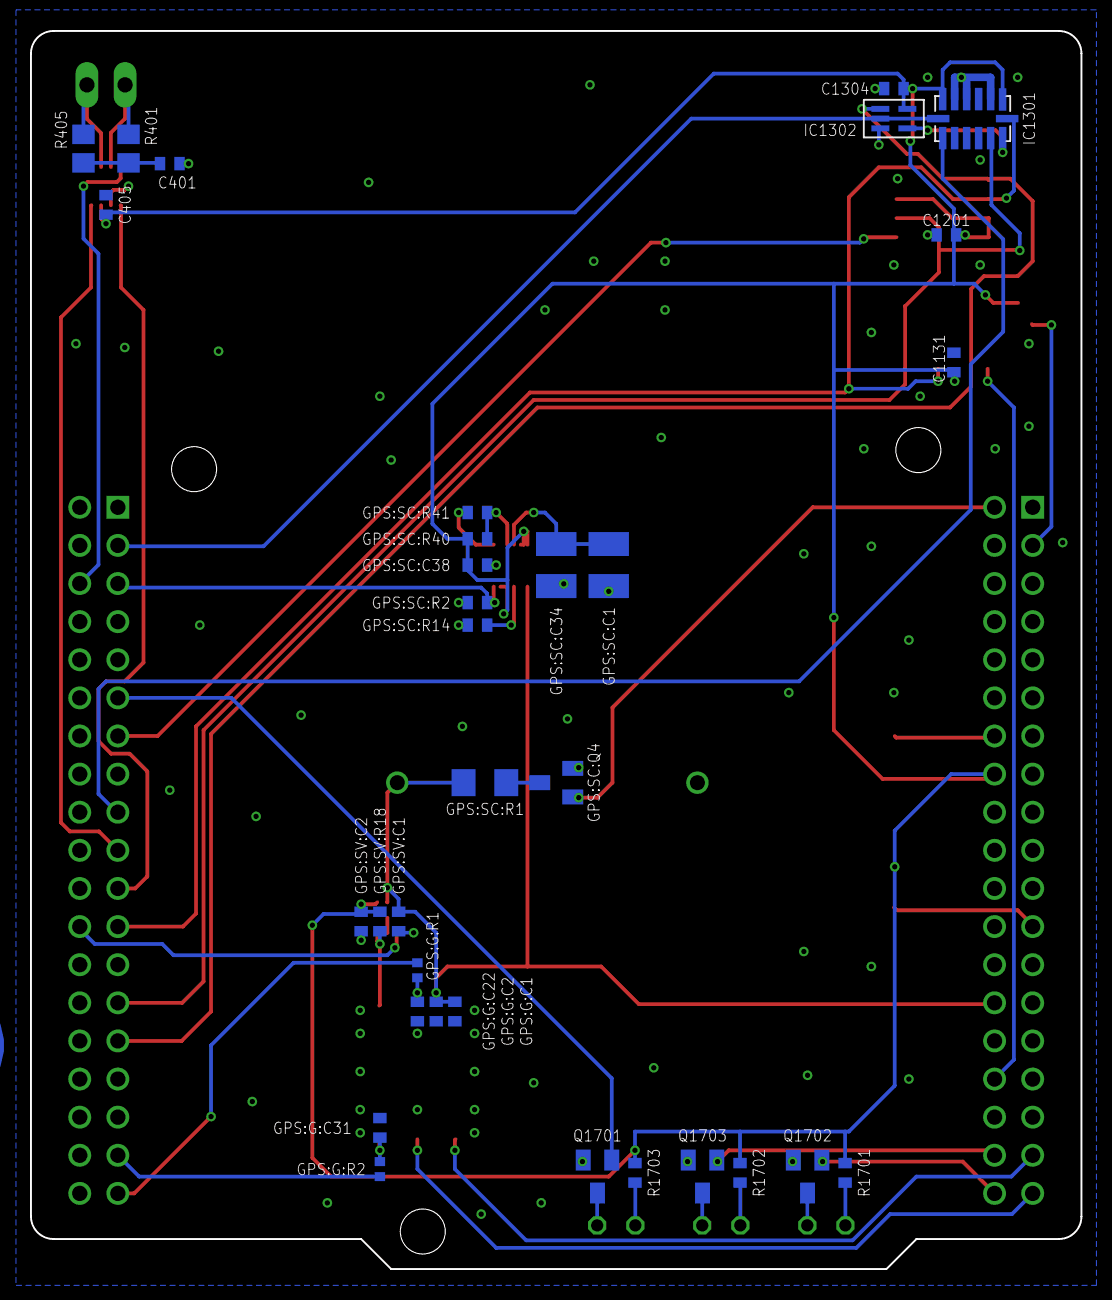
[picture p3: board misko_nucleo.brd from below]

Board: 2 copper layers, 70.0 x 82.5 mm, 48 parts (33 on the bottom side), 44 nets.

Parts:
BRD1: misko; NUCLEO-H503RB-B02
C401: 47nF / 10V; C0402
C405, C1131, C1201, C1304: 0.1u / 16V; C0402
GPS:G:C1: 0.1u / 16V; C0402
GPS:G:C2: 1u / 16V; C0402
GPS:G:C22, GPS:G:C31: 33p / 16V; C0402
GPS:G:IC1: ORG1510-MK4; SMD
GPS:G:R1, GPS:G:R2: 33R; R0402
GPS:SC:C1, GPS:SC:C34: 100u / 16V; C1210
GPS:SC:C24: 1.5F; TH
GPS:SC:C38: 0.1u / 16V; C0402
GPS:SC:IC2: LTC4425EDD#PBF; DFN-12
GPS:SC:JP1: SC override; SJW
GPS:SC:Q4: SQ2310ES-T1_BE3; SOT23
GPS:SC:R1: 33R; R1206
GPS:SC:R2, GPS:SC:R14: 10k; R0402
GPS:SC:R40, GPS:SC:R41: 150k; R0402
GPS:SV:C1, GPS:SV:C2: 0.1u / 16V; C0402
GPS:SV:IC2: TPS3808G33DBVT; WSON-6
GPS:SV:R18: 100k; R0402
IC401: TCAN334; SOT23-8
IC1101: 47309-2651; MICRO_SD_CONNECTOR
IC1201: FM25W256; SOIC08
IC1301: ADXL345; LGA14
IC1302: 74HCT1G32GW; SOT353/5
J1: CAN; 10X02MTA
LED1701: WP710A10SEC; LED2X5
LED1703: WP710A10LZGCK; LED2X5
LED1704: WP710A10SECK/J3; LED2X5
Q1701, Q1702, Q1703: SQ2310ES-T1_BE3; SOT23
R401, R405: 60; R0805
R1701: 55R; R0402
R1702: 65R; R0402
R1703: 33R; R0402
SW1401, SW1402: TL3305CF160QG; SMD

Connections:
3V3: BRD1.CN7_16, C405.1, C1131.1, C1201.1, C1304.1, GPS:SC:C38.1, GPS:SC:IC2.FB, GPS:SC:IC2.SEL, GPS:SC:IC2.VIN1, GPS:SC:IC2.VIN2, GPS:SC:JP1.2, GPS:SC:R40.2, GPS:SV:C2.1, GPS:SV:IC2.VDD, GPS:SV:R18.2, IC401.P$3, IC1101.DET, IC1101.VDD, IC1201.!HOLD!, IC1201.!WP!, IC1201.VCC, IC1301.VCC, IC1301.VDD, IC1302.VCC, R1701.2, R1702.2, R1703.2, SW1402.3, SW1402.4
ADC_VGPS: BRD1.CN7_28, GPS:G:C1.1, GPS:G:C2.1, GPS:G:IC1.4_VCC, GPS:SC:C24.+, GPS:SC:C34.1, GPS:SC:IC2.VOUT1, GPS:SC:IC2.VOUT2, GPS:SC:JP1.1, GPS:SC:R1.2, GPS:SV:C1.1, GPS:SV:IC2.SENSE
ADXL345:ADXL345SDA: IC1301.SDA, IC1302.Y
ADXL345_CS: BRD1.CN10_3, IC1301.!CS!, IC1302.A
ADXL345_INT1: BRD1.CN10_17, IC1301.INT1
CAN_!STBY!: BRD1.CN10_6, IC401.P$8
CAN_H: IC401.P$7, J1.1, R401.2
CAN_INFRA:SPLIT: C401.1, R401.1, R405.2
CAN_L: IC401.P$6, J1.2, R405.1
CAN_RX: BRD1.CN10_19, IC401.P$4
CAN_TX: BRD1.CN10_21, IC401.P$1
GND: BRD1.CN7_8, BRD1.CN7_19, BRD1.CN7_20, BRD1.CN7_22, BRD1.CN10_9, BRD1.CN10_20, BRD1.CN10_32, C401.2, C405.2, C1131.2, C1201.2, C1304.2, GPS:G:C1.2, GPS:G:C2.2, GPS:G:C22.2, GPS:G:C31.2, GPS:G:IC1.5_GND, GPS:G:IC1.GND1, GPS:G:IC1.GND2, GPS:G:IC1.GND4, GPS:G:IC1.GND5, GPS:G:IC1.GND6, GPS:G:IC1.GND7, GPS:G:IC1.GND8, GPS:G:IC1.GND9, GPS:G:IC1.GND10, GPS:G:IC1.GND12, GPS:G:IC1.GND13, GPS:G:IC1.GND14, GPS:G:IC1.GND15, GPS:SC:C1.2, GPS:SC:C24.-, GPS:SC:C38.2, GPS:SC:IC2.GND, GPS:SC:Q4.2, GPS:SC:R2.1, GPS:SC:R14.1, GPS:SV:C1.2, GPS:SV:C2.2, GPS:SV:IC2.GND1, GPS:SV:IC2.GND2, IC401.P$2, IC1101.GND1, IC1101.GND2, IC1101.GND3, IC1201.GND, IC1301.GND1, IC1301.GND2, IC1301.GND3, IC1302.GND, Q1701.2, Q1702.2, Q1703.2, SW1401.3, SW1401.4
GPS:G:GPS_RX: GPS:G:C31.1, GPS:G:IC1.RX_10, GPS:G:R2.2
GPS:G:GPS_TX: GPS:G:C22.1, GPS:G:IC1.3_TX, GPS:G:R1.2
GPS:GPS_ON_OFF: GPS:G:IC1.1_ON_OFF, GPS:SV:IC2.!RESET!, GPS:SV:R18.1
GPS:SC:PFI: GPS:SC:IC2.PFI, GPS:SC:R40.1, GPS:SC:R41.2
GPS:SC:PFI_RET: GPS:SC:IC2.PFI_RET, GPS:SC:R41.1
GPS:SC:PROG: GPS:SC:IC2.PROG, GPS:SC:R14.2
GPS:SC:SC_DIS_DRAIN: GPS:SC:Q4.3, GPS:SC:R1.1
GPS:SC:VMID: GPS:SC:C1.1, GPS:SC:C34.2, GPS:SC:IC2.VMID
GPS_!RESET!: BRD1.CN7_37, GPS:G:IC1.!RESET!_8
GPS_MCU_RX: BRD1.CN10_28, BRD1.CN10_35, GPS:G:R2.1
GPS_MCU_TX: BRD1.CN10_26, BRD1.CN10_37, GPS:G:R1.1
GPS_PWR_CTRL: BRD1.CN10_24, GPS:SV:IC2.!MR!
GPS_WKUP: BRD1.CN7_35, GPS:G:IC1.WAKEUP_6
LED:G_A: LED1703.A, Q1701.3
LED:G_C: LED1703.K, R1703.1
LED:R_A: LED1704.A, Q1702.3
LED:R_C: LED1704.K, R1701.1
LED:Y_A: LED1701.A, Q1703.3
LED:Y_C: LED1701.K, R1702.1
LED_GREEN: BRD1.CN10_11, Q1701.1
LED_RED: BRD1.CN7_38, Q1702.1
LED_YELLOW: BRD1.CN7_36, Q1703.1
NRST: BRD1.CN7_14, SW1401.1, SW1401.2
SD_CD: BRD1.CN7_3, IC1101.POL
SPI1_FRAM_CS: BRD1.CN10_13, IC1201.!CS!
SPI1_MISO: BRD1.CN10_27, IC1101.DAT0, IC1201.SO, IC1301.SDO
SPI1_MOSI: BRD1.CN10_29, IC1101.CMD, IC1201.SI, IC1302.B
SPI1_SCK: BRD1.CN10_23, IC1101.CLK, IC1201.SCK, IC1301.SCL
SPI1_SD_CS: BRD1.CN7_32, IC1101.CD/DAT3
SUPERCAP_!EN!: BRD1.CN10_5, GPS:SC:IC2.EN, GPS:SC:R2.2
SUPERCAP_DISCHARGE: BRD1.CN7_2, GPS:SC:Q4.1
USER_BUTTON: BRD1.CN7_23, SW1402.1, SW1402.2

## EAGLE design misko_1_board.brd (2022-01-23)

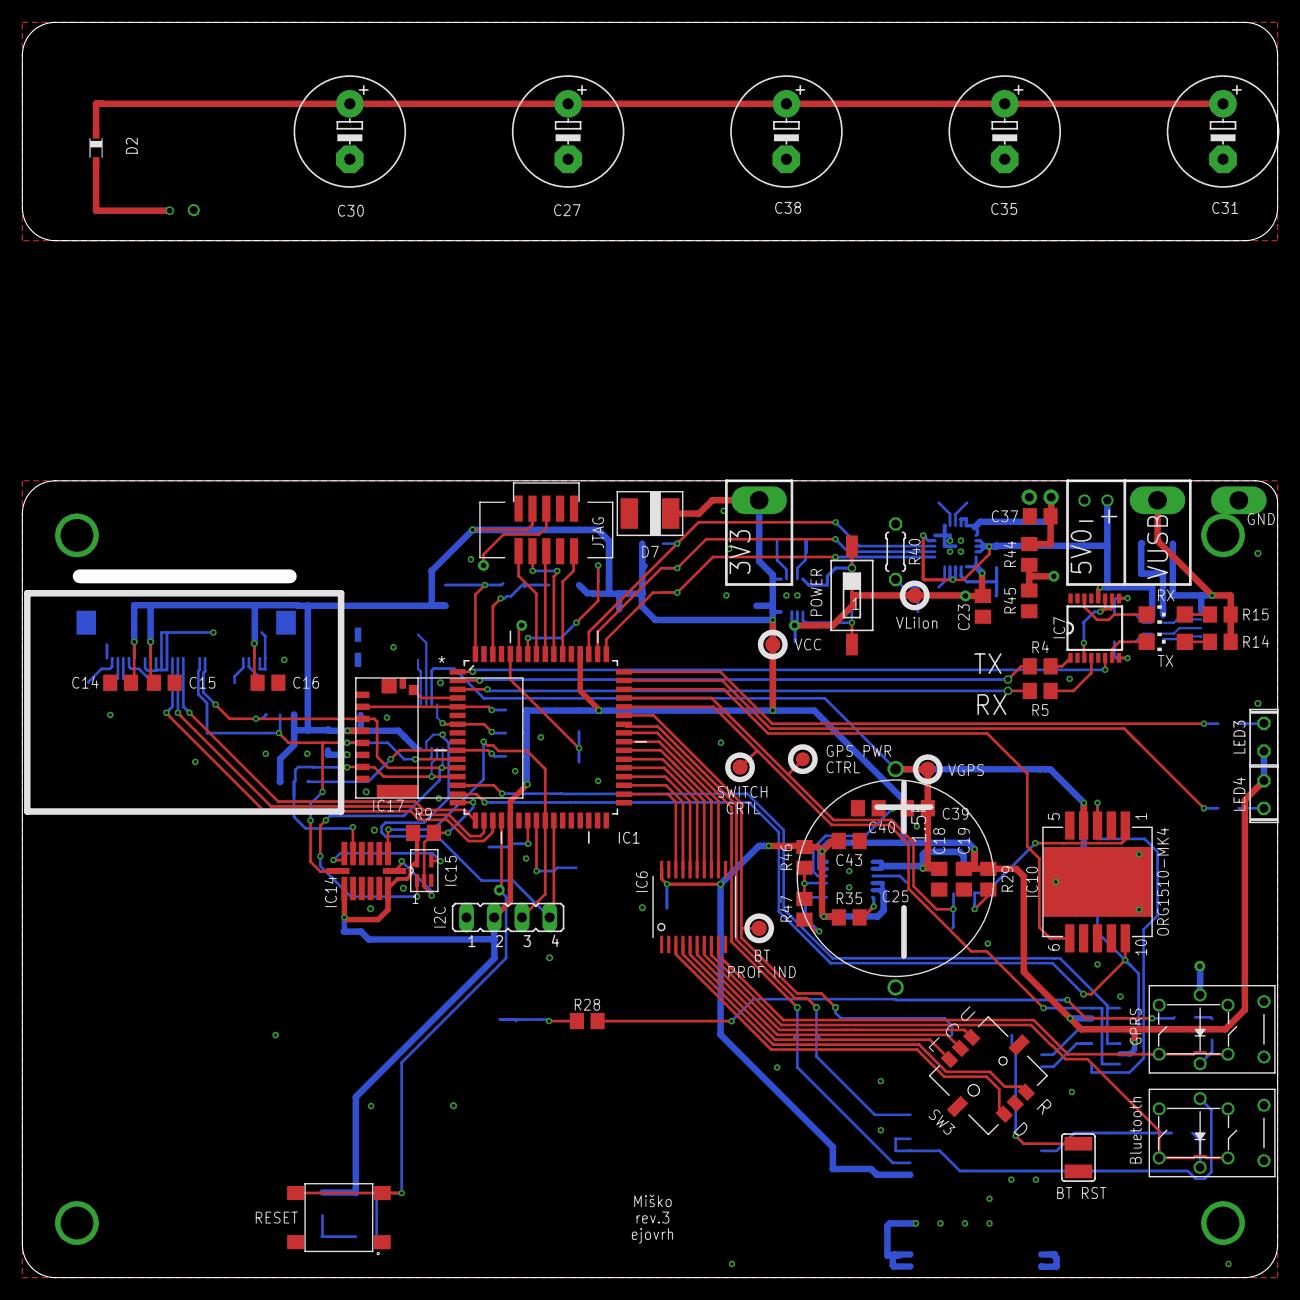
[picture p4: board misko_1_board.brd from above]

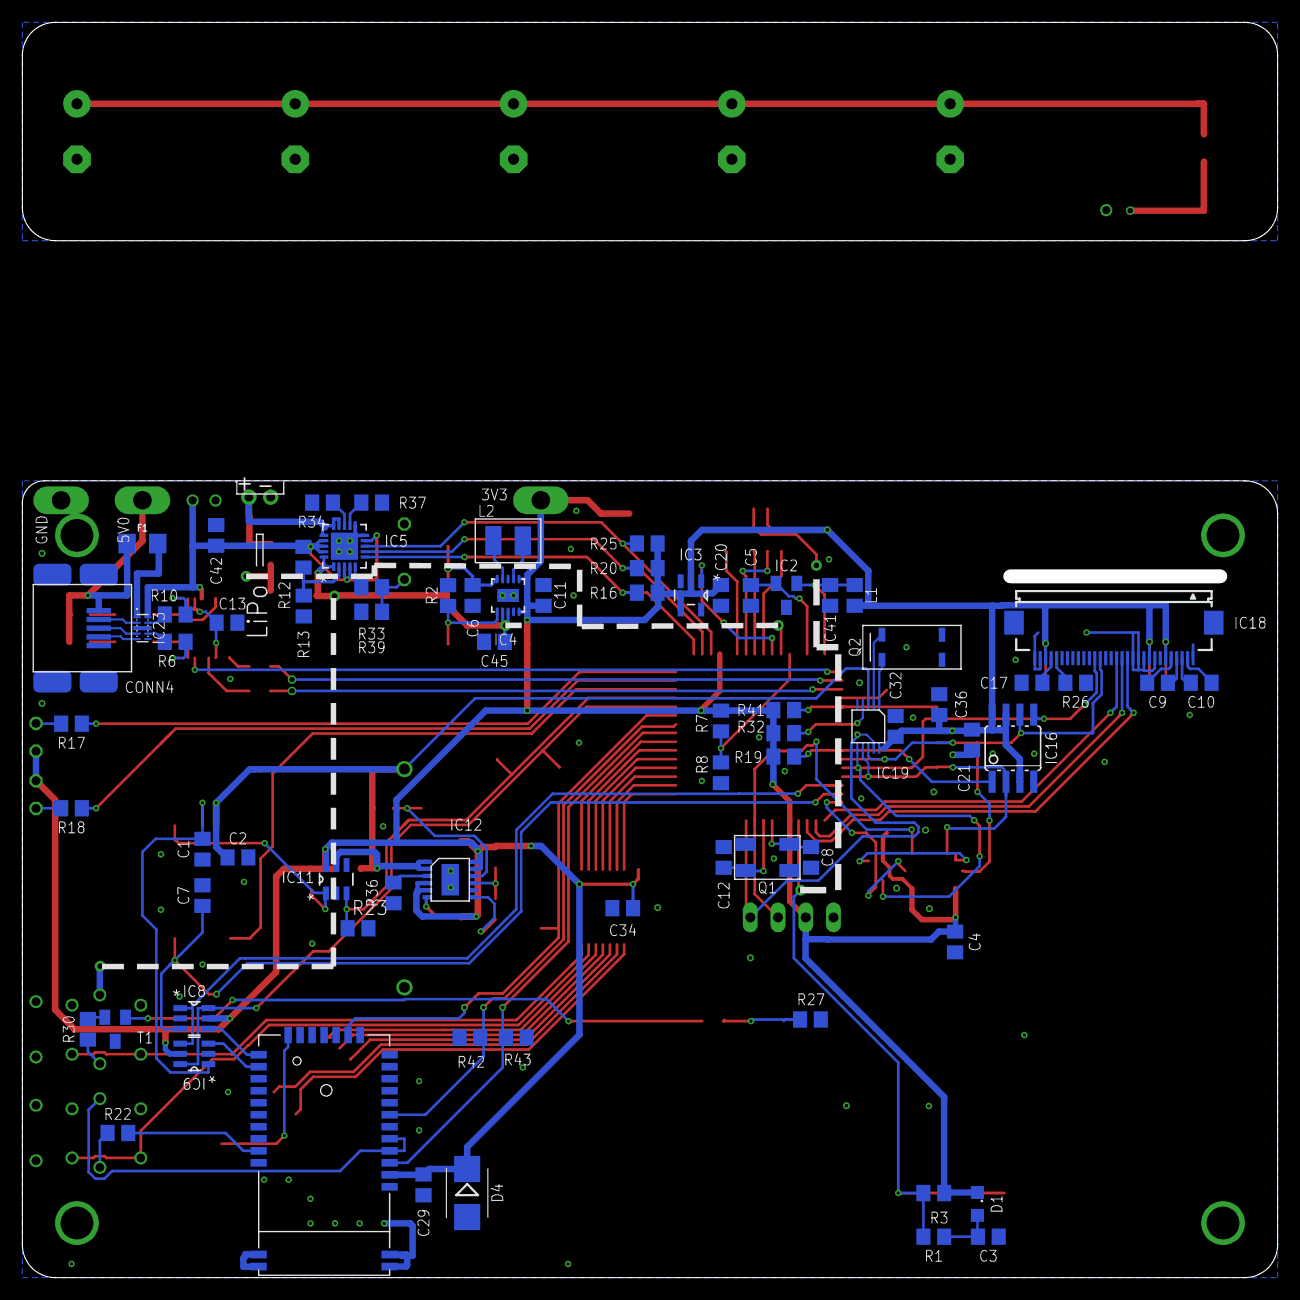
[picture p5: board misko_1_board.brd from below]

Board: 2 copper layers, 115.0 x 73.0 mm, 134 parts (75 on the bottom side), 115 nets.

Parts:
C1, C7: 18pF; C0805
C2, C9, C10, C14, C15: 1µF; C0805
C3, C4, C13, C19, C20, C21, C32, C36, C41, C42, C43, C45: 0.1µF; C0805
C5, C6, C16, C23, C29, C34, C37: 10µF; C0805
C8, C12: 7pF; C0805
C11: 22µF; C0805
C17: 2.2µF / 25V; C0805
C18: 1nF; C0805
C25: 1.5F; TH
C27, C30, C31, C35, C38: 1000µF; E5-10,5
C39, C40: 100µF; C0805
CONN1: JTAG; TH-JTAG
CONN2: I2C; JP4
CONN3: LiPo Battery; JST-PH-2-THM-RA
CONN4: USB mini B; SMT
D1: 1N4148; D0805
D2: BAT60AE6327; SOD323_ST
D4: SZ1SMB5916BT3G; SMB
D7: BZG05C3V6-E3-TR3; DO-214
F1: PTS120615V050; 1206
IC1: ATMEGA1281-16AU; QFP80P1600X1600X120-64N
IC2: MC1525TT; SOT23
IC3: TMP36GRTZ; SOT95P280X145-5N
IC4: TPS63031; SMT
IC5: MCP73871-2AAI/ML; QFN50P400X400X100-21N
IC6: MAX6818; TSSOP20
IC7: FT230XS; SSOP16
IC8: SN74LVC1G3157DBVR - BT switch; SOT95P280X145-6N
IC9: SN74LVC1G3157DBVR - GPS switch; SOT95P280X145-6N
IC10: ORG1510-MK4; PACKAGE
IC11: TPS3808G33DBVT; SOT95P280X145-6N
IC12: LTC4425; MSOP
IC13: RN4678_BT_MODULE; SMT
IC14: ADXL345; LGA14
IC15: 74HCT1G32; SOT353/5
IC16: FM25W256-SOIC; SOIC08
IC17: MICROSD_SPI_MODE; MICRO_SD_CONNECTOR
IC18: FH12-30S-0.5SH
IC19: DS1394U-33+; 10UMAX
IC23: SP3012-04UTG; μDFN-10
L1: DL0805-33 33µH; L0805
L2: DJNR3015-1R5; FFF
LED1: TX; CHIPLED_1206
LED2: RX; CHIPLED_1206
LED3: green; LED2X5
LED4: red; LED2X5
Q1: ABM3B-8MHZ-10-1-U-T; SMT
Q2: LFXTAL016178R; SMD
R1, R16, R20, R25: 47k; R0805
R2, R9, R19, R23, R27, R28, R32, R36, R41, R42, R43: 10k; R0805
R3: 4k7; R0805
R4, R5: 3k3; R0805
R6, R10: 27; R0805
R7, R8, R44, R45: 150k; R0805
R12, R37: 100k; R0805
R13, R39: 270k; R0805
R14, R15, R17, R18, R22, R30, R33, R34, R35: 1k; R0805
R26: 390k; R0805
R29: 1M; R0805
R40: NTC 10k; 0204/5
R46, R47: 470k; R0805
SJ3: RESET; SJW
SW1: RESET; 430152050836
SW2: POWER SWITCH; SMS-001
SW3: MICROJOYSTICK
SW4, SW5: PB6156RSL; TH
T1: BSS84; SOT23
TP1, TP2, TP3: GND; P1-17Y
TP4: VCC; TP14R
TP5: VLiIon Regulated; TP14R
TP6: VGPS; TP14R
TP7: Analogue Switch CRTL Pin; TP14R
TP8: GPS Power CTRL Pin; B1,27
TP11: Bluetooth Wakeup Pin; TP14R

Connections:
5V0: C42.2, D2.A, IC5.3_SEL, IC5.4_PROG2, IC5.9_!TE!, IC5.17_CE, IC5.18_IN1, IC5.19_IN2, IC7.12, IC23.10, R12.1
ADXL345SDA: IC14.SDA, IC15.Y
ADXL345_INT1_INTERRUPT_PIN: CONN2.3, IC1.25, IC14.INT1
ANALOG_SW_CTRL_PIN: IC1.44, IC8.6, IC9.6, TP7.TP
AREF: C5.1, IC1.62, IC2.2
AVCC: C41.2, IC1.64, IC2.1, L1.2
BAT_A_PIN: IC1.59, R44.2, R45.1
BLUETOOTH_PROF_IND_PIN: IC1.43, IC13.P0_5, TP11.TP
BLUETOOTH_RX: IC8.4, IC13.RXD
BLUETOOTH_SWITCH_PIN: IC1.41, IC13.SW_BTN, R43.2
BLUETOOTH_TX: IC9.3, IC13.TXD
BLUETOOTH_WAKEUP_PIN: IC1.42, IC13.WAKEUP, R42.2
BT_LED: IC13.LED, R22.1
BUTTON_BLUETOOTH: IC6.IN7, SW4.3, SW4.4
BUTTON_CENTER: IC6.IN5, SW3.CENTER
BUTTON_DOWN: IC6.IN2, SW3.DOWN
BUTTON_GPRS: IC6.IN8, SW5.3, SW5.4
BUTTON_LEFT: IC6.IN4, SW3.LEFT
BUTTON_RIGHT: IC6.IN3, SW3.RIGHT
BUTTON_UP: IC6.IN6, SW3.UP
CAP1N: C9.1, IC18.5
CAP1P: C9.2, IC18.4
CAP2N: C10.1, IC18.3
CAP2P: C10.2, IC18.2
CBUS1: IC7.14, LED2.C
CBUS2: IC7.7, LED1.C
D+: CONN4.D+, IC23.4
D-: CONN4.D-, IC23.2
EN: IC4.6_EN, R2.2, SW2.1
GND: C1.2, C2.2, C3.1, C4.2, C5.2, C6.1, C7.1, C8.1, C11.1, C12.1, C13.2, C14.1, C15.1, C16.1, C17.1, C18.2, C19.1, C20.2, C21.2, C23.2, C25.-, C27.-, C29.2, C30.-, C31.-, C32.2, C34.2, C35.-, C36.2, C37.2, C38.-, C40.1, C41.1, C42.1, C43.1, C45.2, CONN1.2_GND, CONN1.10_GND, CONN2.1, CONN3.2, CONN4.GND1, CONN4.GND2, CONN4.GND3, CONN4.GND4, CONN4.GND5, D4.A, D7.AN, IC1.22, IC1.53, IC1.63, IC2.3, IC3.5, IC4.3_PGND, IC4.9_GND1, IC4.GND2, IC4.GND3, IC4.GND4, IC5.10_GND1, IC5.11_GND2, IC5.GND2, IC5.GND3, IC5.GND4, IC5.GND5, IC5.GND6, IC6.!EN!, IC6.GND, IC7.5, IC7.13, IC8.2, IC9.2, IC10.GND1, IC10.GND2, IC10.GND3, IC10.GND4, IC10.GND5, IC11.2, IC12.GND1, IC12.GND2, IC12.GND3, IC13.GND, IC13.GND1, IC13.GND2, IC13.GND3, IC13.GND4, IC13.GND5, IC13.GND6, IC13.GND7, IC13.GND8, IC13.GND9, IC13.GND10, IC13.GND11, IC13.GND12, IC14.GND1, IC14.GND2, IC14.GND3, IC15.GND, IC16.GND, IC17.GND2, IC17.GND4, IC17.POL, IC17.VSS, IC18.1, IC18.8, IC18.10, IC18.11, IC18.12, IC18.29, IC18.30, IC19.GND, IC23.3, Q1.GND1, Q1.GND2, R2.1, R8.2, R13.2, R23.2, R26.1, R27.2, R34.2, R36.1, R37.2, R39.2, R40.2, R42.1, R43.1, R45.2, SJ3.2, SW1.1, SW1.3, SW3.GND1, SW3.GND2, SW3.GND3, SW4.1, SW4.2, SW4.GND1, SW4.GND2, SW5.1, SW5.2, SW5.GND1, SW5.GND2, T1.3, TP1.TP
GPRS_NETLIGHT: R27.1, R28.1
GPRS_NETLIGHT_GATE: R28.2, T1.1
GPS_GREEN_LED_PIN: IC1.48, R17.1
GPS_ON_OFF: IC10.ON_OFF, IC11.1, R29.1
GPS_POWER_CTL_PIN: IC1.45, IC11.3, R23.1, TP8.TP
GPS_RED_LED_PIN: IC1.47, R18.1
GPS_SW_SERIAL_RX: IC1.14, IC8.1, IC9.4
GPS_SW_SERIAL_TX: C7.2, IC1.15, IC8.3, IC10.RX
GPS_TX: C1.1, IC9.1, IC10.TX
GPS_WAKEUP_PIN: IC1.46, IC10.WAKEUP
GREEN_LED: LED3.K, R17.2
ID: CONN4.ID, IC23.5
IREF: IC18.26, R26.2
JTAG_TCL_PIN: CONN1.1_JTAG_TCK, IC1.57
JTAG_TDI_PIN: CONN1.9_JTAG_TDI, IC1.54
JTAG_TDO_PIN: CONN1.3_JTAG_TDO, IC1.55
JTAG_TMS_PIN: CONN1.5_JTAG_TMS, IC1.56
L2: R22.2, SW4.L2
LDO33_O: IC13.LDO33_O, IC13.VDD_IO, SW4.L1
LTC4425_EN: IC12.EN, R35.2
LTC4425_PROG: IC12.PROG, R36.2
L_L1: IC4.4_L1, L2.P$1
L_L2: IC4.2_L2, L2.P$2
MCP73871_CHARGE_STATUS_1_PIN: IC1.51, IC5.8_STAT1, R25.2
MCP73871_CHARGE_STATUS_2_PIN: IC1.50, IC5.7_STAT2, R20.2
MCP73871_POWER_GOOD_PIN: IC1.49, IC5.!6_PG!, R16.2
MENU_BLUETOOTH_POWER_BUTTON_PIN: IC1.39, IC6.OUT7
MENU_CENTER_BUTTON_PIN: IC1.37, IC6.OUT5
MENU_DOWN_BUTTON_PIN: IC1.34, IC6.OUT2
MENU_GPRS_POWER_BUTTON_PIN: IC1.40, IC6.OUT8
MENU_LEFT_BUTTON_PIN: IC1.36, IC6.OUT4
MENU_RIGHT_BUTTON_PIN: IC1.35, IC6.OUT3
MENU_UP_BUTTON_PIN: IC1.38, IC6.OUT6
unnamed: R30.1, SW5.L2
unnamed: R30.2, T1.2
unnamed: F1.2, IC23.1
unnamed: C27.+, C30.+, C31.+, C35.+, C38.+, D2.C
unnamed: C13.1, IC7.3, IC7.10, IC7.11
unnamed: IC13.!RST_N!, SJ3.1
unnamed: R33.2, R39.1, R40.1
unnamed: C3.2, D1.A, R1.1
PDI_UART0_CTS_PIN: IC1.1, IC7.6
PDI_UART0_RX_PIN: IC1.2, R4.1
PDI_UART0_TX_PIN: IC1.3, R5.1
PFI: IC12.PFI, R46.1, R47.2
PFI_RET: IC12.PFI_RET, R47.1
PROG1: IC5.13_PROG1, R34.1
PROG3: IC5.12_PROG3, R37.1
RED_LED: LED4.K, R18.2
RESET: CONN1.6_JTAG_RST, IC1.20, R1.2, R3.2, SW1.2, SW1.4
RTC_INT_INTERRUPT_PIN: CONN2.4, IC1.26, IC19.!INT!
RTC_XTAL1: IC19.X1, Q2.XTAL1
RTC_XTAL2: IC19.X2, Q2.XTAL2
RXD: IC7.4, R5.2
SD_CARD_DETECT_PIN: IC1.4, IC17.DET
SPI_MISO_PIN: IC1.13, IC14.SDO, IC16.SO, IC17.DAT0, IC19.DOUT
SPI_MOSI_PIN: IC1.12, IC15.B, IC16.SI, IC17.CMD, IC18.19, IC19.DIN
SPI_OLED_D/C_PIN: IC1.17, IC18.15
SPI_OLED_RESET_PIN: IC1.18, IC18.14
SPI_SCK_PIN: IC1.11, IC14.SCL, IC16.SCK, IC17.CLK, IC18.18, IC19.SCLK
SPI_SS_ADXL345_PIN: IC1.16, IC14.!CS!, IC15.A, R9.2
SPI_SS_FRAM_PIN: IC1.10, IC16.!CS!, R19.1
SPI_SS_OLED_PIN: IC1.19, IC18.13
SPI_SS_RTC_PIN: IC1.7, IC19.!CS!, R32.2
SPI_SS_SD_CARD_PIN: IC1.5, IC17.CD/DAT3, R41.1
THERM: IC5.5_THERM, R33.1
TMP36_VSENSE_PIN: IC1.58, IC3.1
TXD: IC7.1, R4.2
USBDM: IC7.9, R10.1
USBDP: IC7.8, R6.2
USB_D+: IC23.7, R6.1
USB_D-: IC23.9, R10.2
USB_RX_LED: LED1.A, R14.2
USB_TX_LED: LED2.A, R15.2
VCC: C4.1, C11.2, C14.2, C15.2, C16.2, C19.2, C20.1, C21.1, C29.1, C32.1, C34.1, C36.1, C43.2, CONN1.4_VCC, CONN2.2, D1.C, D4.C, D7.CAT, IC1.21, IC1.52, IC3.2, IC3.4, IC4.1_VOUT, IC4.10_FB, IC6.VCC, IC8.5, IC9.5, IC11.6, IC12.FB, IC12.SEL, IC12.VIN1, IC12.VIN2, IC13.BAT_IN, IC14.VCC, IC14.VDD, IC15.VCC, IC16.!HOLD!, IC16.!WP!, IC16.VCC, IC17.VDD, IC18.6, IC18.9, IC18.28, IC19.VCC, L1.1, LED3.A, LED4.A, R3.1, R7.1, R9.1, R16.1, R19.2, R20.1, R25.1, R29.2, R32.1, R35.1, R41.2, R46.2, TP3.TP, TP4.TP
VCC_SENSE_PIN: IC1.60, R7.2, R8.1
VCOMH: C17.2, IC18.27
VGPS: C2.1, C18.1, C25.+, C39.1, IC10.VCC, IC11.5, IC12.VOUT1, IC12.VOUT2, IC19.VBACK, TP6.TP
VMID: C39.2, C40.2, IC12.VMID
VPCC: IC5.2_VPCC, R12.2, R13.1
VUSB: CONN4.VBUS, F1.1, R14.1, R15.1, TP2.TP
V_LIION+: C37.1, CONN3.1, IC5.14_VBAT1, IC5.15_VBAT2, IC5.16_BAT_SENSE, R44.1
V_LIION_REGULATED: C6.2, C23.1, C45.1, IC4.5_VIN, IC4.7_PS/SYNC, IC4.8_VINA, IC5.1_OUT1, IC5.20_OUT2, SW2.2, SW5.L1, TP5.TP
XTAL1: C12.2, IC1.24, Q1.Q2
XTAL2: C8.2, IC1.23, Q1.Q1

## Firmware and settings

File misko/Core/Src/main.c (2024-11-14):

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
/* Includes ------------------------------------------------------------------*/
#include "main.h"

/* USER CODE BEGIN Includes */
#include "lwrb/lwrb.h"	// LightWeight Ringbuffer

#if USE_ADXL345
#include "adxl345/adxl345.h"
#endif
#if USE_FM25W256
#include "fm25w256/fm25w256.h"
#endif
#if USE_SD
#include "sd/sd.h"
#endif
#if USE_ORG1510MK4
#include "org1510mk4/org1510mk4.h"
#endif
#if USE_TIMEHELPER
#include "timehelper/timehelper.h"
#endif
#if USE_LOGGER
#include "logger/logger.h"
#endif
/* USER CODE END Includes */

/* USER CODE BEGIN PD */
#define DEBUG_SYS_RX_RB_FREE 1 // data member indicating LwRB free space

#define UART3_SYS_RX_DMA_BUFFER_LEN 32	// circular DMA RX buffer length for incoming GPS UART DMA data
#define UART3_SYS_RX_RINGBUFFER_LEN 256	// ringbuffer size
/* USER CODE END PD */

ADC_HandleTypeDef hadc1;
DMA_NodeTypeDef Node_GPDMA1_Channel5;
DMA_QListTypeDef List_GPDMA1_Channel5;
DMA_HandleTypeDef handle_GPDMA1_Channel5;

FDCAN_HandleTypeDef hfdcan1;

DMA_HandleTypeDef handle_GPDMA1_Channel7;
DMA_HandleTypeDef handle_GPDMA1_Channel6;

I2C_HandleTypeDef hi2c2;
DMA_HandleTypeDef handle_GPDMA2_Channel1;
DMA_HandleTypeDef handle_GPDMA2_Channel0;

RTC_HandleTypeDef hrtc;

SPI_HandleTypeDef hspi1;

TIM_HandleTypeDef htim1;
TIM_HandleTypeDef htim2;

UART_HandleTypeDef huart1;
UART_HandleTypeDef huart3;
DMA_NodeTypeDef Node_GPDMA1_Channel3;
DMA_QListTypeDef List_GPDMA1_Channel3;
DMA_HandleTypeDef handle_GPDMA1_Channel3;
DMA_NodeTypeDef Node_GPDMA1_Channel1;
DMA_QListTypeDef List_GPDMA1_Channel1;
DMA_HandleTypeDef handle_GPDMA1_Channel1;
DMA_HandleTypeDef handle_GPDMA1_Channel0;

PCD_HandleTypeDef hpcd_USB_DRD_FS;

/* USER CODE BEGIN PV */
static lwrb_t uart3_sys_rx_rb;  // 2nd circular buffer for data processing
static uint8_t uart3_sys_rx_rb_buffer[UART3_SYS_RX_RINGBUFFER_LEN];  //
static uint8_t uart3_sys_rx_dma_buffer[UART3_SYS_RX_DMA_BUFFER_LEN];  //

static uint8_t VCPTxBuffer[82] = "\rnucleo-h503rb start\r\n";

volatile uint32_t __adc_dma_buffer[ADC_CHANNELS] =  // store for ADC readout
	{0};
volatile uint32_t __adc_results[ADC_CHANNELS] =  // store ADC average data
	{0};
double _VddaConversionConstant;  // constant values pre-computed in main()

static uint8_t SYS_out[82] = "\0";  // output box for GPS UART's DMA

#if DEBUG_LWRB_FREE
uint16_t uart3_lwrb_free;  // ringbuffer free memory
uint32_t uart3_char_written;	// characters written
lwrb_sz_t uart3_ovrflowlen;  // amount of data written in overflow mode
lwrb_sz_t uart3_linearlen;  // amount of data written in linear mode
#endif
logger_t *mj8x8_log;	// logger object for mj8x8 data
logger_t *gps_log;	// logger object for GPS data
/* USER CODE END PV */

void SystemClock_Config(void);
void PeriphCommonClock_Config(void);
static void MPU_Config(void);
static void MX_GPIO_Init(void);
static void MX_GPDMA1_Init(void);
static void MX_GPDMA2_Init(void);
static void MX_ICACHE_Init(void);
static void MX_USB_PCD_Init(void);
static void MX_USART3_UART_Init(void);
static void MX_TIM1_Init(void);
static void MX_SPI1_Init(void);
static void MX_FDCAN1_Init(void);
static void MX_ADC1_Init(void);
static void MX_USART1_UART_Init(void);
static void MX_I2C2_Init(void);
static void MX_TIM2_Init(void);
static void MX_RTC_Init(void);
/* USER CODE BEGIN 0 */
static void load_into_ring_buffer(lwrb_t *rb, const uint16_t high_pos)
{
	static uint16_t low_pos;

	// safeguard against an RX event interrupt where no new data has come in
	if(high_pos == low_pos)  // no new data
		return;

	// 1st buffering - load into ringbuffer
	if(high_pos > low_pos)  // linear region
		// read in a linear fashion from DMA rcpt. buffer from beginning to end of new data
		lwrb_write(rb, &uart3_sys_rx_dma_buffer[low_pos], high_pos - low_pos);  // (high_pos - low_pos) is length of new data
	else	// overflow region
		{
			// read new data from current position until end of DMA rcpt. buffer
			lwrb_write(&uart3_sys_rx_rb, &uart3_sys_rx_dma_buffer[low_pos], UART3_SYS_RX_DMA_BUFFER_LEN - low_pos);

			// then, if there is more after the rollover
			if(high_pos > 0)
				// read from beginning of circular DMA buffer until the end position of new data
				lwrb_write(rb, &uart3_sys_rx_dma_buffer[0], high_pos);
		}

	low_pos = high_pos;  // save position until data has been read

#if DEBUG_SYS_RB_FREE
	uart3_lwrb_free = (uint16_t) lwrb_get_free(&uart3_sys_rx_rb);  // have free memory value visible

	if(uart3_lwrb_free == 0)  // LwRB memory used up: hang here
		Error_Handler();
#endif
}
/* USER CODE END 0 */

/**
 * @brief  The application entry point.
 * @retval int
 */
int main(void)
{

	/* MCU Configuration--------------------------------------------------------*/

	/* MPU Configuration--------------------------------------------------------*/
	MPU_Config();

	/* Reset of all peripherals, Initializes the Flash interface and the Systick. */
	HAL_Init();

	/* Configure the system clock */
	SystemClock_Config();

	/* Configure the peripherals common clocks */
	PeriphCommonClock_Config();

	/* Initialize all configured peripherals */
	MX_GPIO_Init();
	MX_GPDMA1_Init();
	MX_GPDMA2_Init();
	MX_ICACHE_Init();
	MX_USB_PCD_Init();
	MX_USART3_UART_Init();
	MX_TIM1_Init();
	MX_SPI1_Init();
	MX_FDCAN1_Init();
	MX_ADC1_Init();
	MX_USART1_UART_Init();
	MX_I2C2_Init();
	MX_TIM2_Init();
	MX_RTC_Init();
	/* USER CODE BEGIN 2 */

	// 125ms time base
	if(HAL_TIM_OC_Start_IT(&htim1, TIM_CHANNEL_1) != HAL_OK)
		Error_Handler();

	// start ADC
	_VddaConversionConstant = (VREFINT_CAL_VREF * *VREFINT_CAL_ADDR) / 4095.0;  // 1203.95604
	HAL_ADC_Start_DMA(&hadc1, (uint32_t*) __adc_dma_buffer, ADC_CHANNELS);

	// SPI DMA stuff
	MX_Queue_tx_Config();
	HAL_DMAEx_List_LinkQ(&handle_GPDMA1_Channel7, &Queue_tx);
	__HAL_LINKDMA(&hspi1, hdmatx, handle_GPDMA1_Channel7);
	MX_Queue_rx_Config();
	HAL_DMAEx_List_LinkQ(&handle_GPDMA1_Channel6, &Queue_rx);
	__HAL_LINKDMA(&hspi1, hdmarx, handle_GPDMA1_Channel6);

	// transmit hello world over VCP
	if(HAL_UART_Transmit_DMA(&huart3, (uint8_t*) VCPTxBuffer, (uint16_t) strlen((const char*) VCPTxBuffer)) != HAL_OK)
		Error_Handler();

	// initialize the ringbuffer and ...
	lwrb_init(&uart3_sys_rx_rb, uart3_sys_rx_rb_buffer, sizeof(uart3_sys_rx_rb_buffer));

	// ... start to receive whatever from VCP
	if(HAL_OK != HAL_UARTEx_ReceiveToIdle_DMA(&huart3, uart3_sys_rx_dma_buffer, UART3_SYS_RX_DMA_BUFFER_LEN))  // start reception)
		Error_Handler();

	// start peripheral devices
#if USE_ADXL345
	adxl345_ctor(&hspi1, SPI1_ADXL345_CS_GPIO_Port, SPI1_ADXL345_CS_Pin);  // initialize accelerometer object
#endif
#if USE_FM25W256
	fm25w256_ctor(&hspi1, SPI1_FRAM_CS_GPIO_Port, SPI1_FRAM_CS_Pin);  //initialize FeRAM object
#endif
#if USE_SD
	sd_ctor(&hspi1, SPI1_SD_CS_GPIO_Port, SPI1_SD_CS_Pin, SD_CD_GPIO_Port, SD_CD_Pin);  // initialize SD Card object
#endif
#if USE_ORG1510MK4
	org1510mk4_ctor(&huart1, &huart3);  // initialise the GPS module object
#endif
#if USE_TIMEHELPER
	timehelper_ctor(ORG1510MK4, &hrtc);  // initialize TimeHelper object
#endif
#if USE_LOGGER
	mj8x8_log = logger_ctor();
	gps_log = logger_ctor();
#endif
	/* USER CODE END 2 */

	/* Infinite loop */
	/* USER CODE BEGIN WHILE */
	while(1)
		{
#if PARSE_GSV
			ORG1510MK4->AlmEphQuery();	// asynchronous flag_alm_eph_query for SV almanac & ephemeris
#endif
			TimeHelper->TimeHelper(ORG1510MK4->FlagTimeAccurate);  // deal with time...
#if PARSE_PMTK
			TimeHelper->LocationHelper(0);  // seed the last known location
#endif
			/* USER CODE END WHILE */

			/* USER CODE BEGIN 3 */
		}
	/* USER CODE END 3 */
}

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
/* USER CODE BEGIN 4 */

// EXTI rising edge callback
void HAL_GPIO_EXTI_Rising_Callback(uint16_t GPIO_Pin)
{
	if(GPIO_Pin == Blue_User_Button_Pin)  // if button is pressed
		{
			HAL_GPIO_TogglePin(LED_Red_GPIO_Port, LED_Red_Pin);
			return;
		}

#if USE_ADXL345
	if(GPIO_Pin == ADXL345_INT1_Pin)  // accelerometer interrupt (act. or inact.)
		{
			ADXL345->ISR();  // execute the ISR callback
			return;
		}
#endif
}

// EXTI falling edge callback
void HAL_GPIO_EXTI_Falling_Callback(uint16_t GPIO_Pin)
{
	if(GPIO_Pin == SD_CD_Pin)  // if card is removed
		{
			;  // TODO - SD card detect irq - implement disable read/write operations
			// TODO - SD card detect irq - also make sure that before any read/write, this GPIO state is checked
		}
}

// UART complete reception
void HAL_UART_RxCpltCallback(UART_HandleTypeDef *huart)
{
	if(huart == &huart1)
		{
			;
		}

	if(huart == &huart3)
		{
			;
		}
}

// UART RX events - RX Half-Complete/Complete & idle line interrupts
void HAL_UARTEx_RxEventCallback(UART_HandleTypeDef *huart, uint16_t Size)
{
	if(huart == &huart1)
		{
			ORG1510MK4->Parse(Size);
		}

	if(huart == &huart3)
		{
			load_into_ring_buffer(&uart3_sys_rx_rb, Size);  // buffer incoming UART stream into ring buffer

			lwrb_sz_t bytes_in_rb = lwrb_get_full(&uart3_sys_rx_rb);

			if(bytes_in_rb)
				{
					char c = 0;
					lwrb_peek(&uart3_sys_rx_rb, bytes_in_rb - 1, &c, 1);

					if(c == '\r')
						{
							lwrb_read(&uart3_sys_rx_rb, SYS_out, bytes_in_rb);
							uint8_t len = (uint8_t) strlen((const char*) SYS_out);
							SYS_out[len - 1] = '\0';

							if(!(SYS_out[0] >= 'A' && SYS_out[0] <= 'Z'))  // crude filter against non-printable characeters in input
								{
									memset(SYS_out, '\0', 82);  // zero out out-container
									return;
								}

							ORG1510MK4->Write((const char*) SYS_out);
							memset(SYS_out, '\0', 82);  // zero out out-container
							return;
						}

					lwrb_peek(&uart3_sys_rx_rb, bytes_in_rb - 2, &c, 1);
					if(c == '\e')  // ALT and some key below...
						{
							lwrb_peek(&uart3_sys_rx_rb, bytes_in_rb - 1, &c, 1);

							switch(c)
								{
								case '0':  // ALT + 0
									ORG1510MK4->Power(off);
									break;

								case '1':  // ALT + 1
									ORG1510MK4->Power(on);
									break;

								case '2':
									ORG1510MK4->Power(backup);
									break;

								case '3':
									ORG1510MK4->Power(wakeup);
									break;

								case '4':
									ORG1510MK4->Power(standby);
									break;

								case '5':
									ORG1510MK4->Power(periodic);
									break;

								case '6':
									ORG1510MK4->Power(alwayslocate);
									break;

								case '7':
									ORG1510MK4->Power(reset);
									break;

								case '8':
									ORG1510MK4->Power(discharge);
									break;

								case 'r':
									ORG1510MK4->Power(off);
									NVIC_SystemReset();
									break;

								case 'q':
									TimeHelper->LocationHelper(1);	// force location seed
									break;

								default:
									return;
								}
						}
				}
		}
}
/* USER CODE END 4 */

/* MPU Configuration */

void MPU_Config(void)
{
	MPU_Region_InitTypeDef MPU_InitStruct =
		{0};
	MPU_Attributes_InitTypeDef MPU_AttributesInit =
		{0};

	/* Disables the MPU */
	HAL_MPU_Disable();

	/** Initializes and configures the Region and the memory to be protected
	 */
	MPU_InitStruct.Enable = MPU_REGION_ENABLE;
	MPU_InitStruct.Number = MPU_REGION_NUMBER0;
	MPU_InitStruct.BaseAddress = 0x08FFF810;
	MPU_InitStruct.LimitAddress = 0x08FFF819;
	MPU_InitStruct.AttributesIndex = MPU_ATTRIBUTES_NUMBER0;
	MPU_InitStruct.AccessPermission = MPU_REGION_ALL_RO;
	MPU_InitStruct.DisableExec = MPU_INSTRUCTION_ACCESS_DISABLE;
	MPU_InitStruct.IsShareable = MPU_ACCESS_NOT_SHAREABLE;

	HAL_MPU_ConfigRegion(&MPU_InitStruct);
	MPU_AttributesInit.Number = MPU_REGION_NUMBER0;
	MPU_AttributesInit.Attributes = MPU_DEVICE_nGnRnE | MPU_WRITE_THROUGH | MPU_TRANSIENT | MPU_NO_ALLOCATE;

	HAL_MPU_ConfigMemoryAttributes(&MPU_AttributesInit);
	/* Enables the MPU */
	HAL_MPU_Enable(MPU_HFNMI_PRIVDEF);

}

/**
 * @brief  This function is executed in case of error occurrence.
 * @retval None
 */
void Error_Handler(void)
{
	/* USER CODE BEGIN Error_Handler_Debug */
	/* User can add his own implementation to report the HAL error return state */
	__disable_irq();
	while(1)
		{
		}
	/* USER CODE END Error_Handler_Debug */
}

#ifdef  USE_FULL_ASSERT
/**
  * @brief  Reports the name of the source file and the source line number
  *         where the assert_param error has occurred.
  * @param  file: pointer to the source file name
  * @param  line: assert_param error line source number
  * @retval None
  */
void assert_failed(uint8_t *file, uint32_t line)
{
  /* USER CODE BEGIN 6 */
  /* User can add his own implementation to report the file name and line number,
     ex: printf("Wrong parameters value: file %s on line %d\r\n", file, line) */
  /* USER CODE END 6 */
}
#endif /* USE_FULL_ASSERT */

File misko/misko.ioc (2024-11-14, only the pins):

Mcu.UserName=STM32H503RBTx
PA0.GPIO_Label=ADC_VGPS
PA0.Signal=ADCx_INP0
PA1.GPIO_Label=ROTARY_CH2
PA1.Signal=S_TIM2_CH2
PA11.GPIO_Label=USB_FS_DN
PA11.Signal=USB_DM
PA12.GPIO_Label=USB_FS_DP
PA12.Signal=USB_DP
PA13(JTMS/SWDIO).GPIO_Label=SWDIO
PA13(JTMS/SWDIO).Signal=DEBUG_JTMS-SWDIO
PA14(JTCK/SWCLK).GPIO_Label=SWCLK
PA14(JTCK/SWCLK).Signal=DEBUG_JTCK-SWCLK
PA15(JTDI).GPIO_Label=JTDI
PA15(JTDI).Signal=DEBUG_JTDI
PA2.GPIO_Label=SPI1_SD_CS
PA2.Signal=GPIO_Output
PA3.GPIO_Label=UART3_VCP_RX
PA3.Signal=USART3_RX
PA4.GPIO_Label=UART3_VCP_TX
PA4.Signal=USART3_TX
PA5.GPIO_Label=LED_Green
PA5.Signal=GPIO_Output
PA6.GPIO_Label=SPI1_FRAM_CS
PA6.Signal=GPIO_Output
PA8.GPIO_Label=SPI1_SCK
PA8.Signal=SPI1_SCK
PA9.GPIO_Label=USB_FS_VBUS
PA9.Signal=GPIO_Input
PB10.GPIO_Label=I2C2_SCL
PB10.Signal=I2C2_SCL
PB12.GPIO_Label=CAN_STBY
PB12.Signal=GPIO_Output
PB13.GPIO_Label=I2C2_SDA
PB13.Signal=I2C2_SDA
PB14.GPIO_Label=UART1_TX
PB14.Signal=USART1_TX
PB15.GPIO_Label=UART1_RX
PB15.Signal=USART1_RX
PB2.GPIO_Label=ROTARY_CH1
PB2.Signal=S_TIM2_CH1
PB3(JTDO/TRACESWO).GPIO_Label=SWO
PB3(JTDO/TRACESWO).Signal=DEBUG_JTDO-SWO
PB4(NJTRST).GPIO_Label=SPI1_MISO
PB4(NJTRST).Signal=SPI1_MISO
PB5.GPIO_Label=SPI1_MOSI
PB5.Signal=SPI1_MOSI
PB6.GPIO_Label=SPI1_ADXL345_CS
PB6.Signal=GPIO_Output
PB7.GPIO_Label=SUPERCAP_EN
PB7.Signal=GPIO_Output
PB8.GPIO_Label=Anal_SW_CTRL
PB8.Signal=GPIO_Output
PC0.GPIO_Label=LED_Red
PC0.Signal=GPIO_Output
PC1.GPIO_Label=LED_Yellow
PC1.Signal=GPIO_Output
PC10.GPIO_Label=USB_FS_PWR_EN
PC10.Signal=GPIO_Output
PC11.GPIO_Label=SUPERCAP_DISCHARGE
PC11.Signal=GPIO_Output
PC12.GPIO_Label=SD_CD
PC12.Signal=GPIO_Input
PC13.GPIO_Label=Blue_User_Button
PC13.Signal=GPXTI13
PC14-OSC32_IN(OSC32_IN).Signal=RCC_OSC32_IN
PC15-OSC32_OUT(OSC32_OUT).Signal=RCC_OSC32_OUT
PC2.GPIO_Label=GPS_WKUP
PC2.Signal=GPIO_Input
PC3.GPIO_Label=GPS_RESET
PC3.Signal=GPIO_Output
PC4.GPIO_Label=GPS_PWR_CTRL
PC4.Signal=GPIO_Output
PC6.GPIO_Label=CAN_RX
PC6.Signal=FDCAN1_RX
PC7.GPIO_Label=CAN_TX
PC7.Signal=FDCAN1_TX
PC8.GPIO_Label=Debug_Out
PC8.Signal=GPIO_Output
PC9.GPIO_Label=ADXL345_INT1
PC9.Signal=GPXTI9
PD2.GPIO_Label=USB_FS_OVCR
PD2.Signal=GPXTI2
PH0-OSC_IN(PH0).Signal=RCC_OSC_IN
PH1-OSC_OUT(PH1).Signal=RCC_OSC_OUT

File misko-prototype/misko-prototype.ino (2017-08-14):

// libraries
#include <SoftwareSerial.h> // software serial library for GPS/Bluetooth
#include <SD.h> // SD card library
#include <SPI.h> // SPI library
#include <U8glib.h> // OLED chip driver - https://github.com/olikraus/u8glib/wiki/userreference
#include <M2tk.h> // user menu library - https://code.google.com/archive/p/m2tklib/
#include "utility/m2ghu8g.h" // U8glib graphics handler (one of many)
#include "utility/mas.h" // mass storage handler for the SD card
#include <gprs.h> // GPRS library for SIM800C
#include <WiFi101.h>
#include <avr/sleep.h> // AVR sleep management
#include <avr/power.h> // AVR power saving

// local files
#include "adxl345.h" // definition of ADXL345 register addresses
#include "fram.h" // definition of FRAM register addresses & addressing scheme for config settins
#include "pin_definitions.h" // pin layout
#include "global_variables.h" // global variables et al.
#include "functions.h" // useful functions
#include "display.h" // display (menu) code

void setup()
{
	#include "pin_modes.h" // definiton of pin modes
  #include "setup.h" // the actual setup [ without () ]
}

#include "gps_functions.h" // gps functions - kludge alert!

void loop()
{
  #include "loop.h" // the actual loop [ without () ]
}

// ISR names
//	http://www.nongnu.org/avr-libc/user-manual/group__avr__interrupts.html

//ISR for the ADXL345 accelerometer
ISR(INT7_vect)
{
	cli();
	adxl345_irq_src = adxl345_readByte(INT_SOURCE);

	// inactivity
	if( (adxl345_irq_src >> 3) & 0x01)  // if the inact bit is set
	{
		Serial.println("Inactivity");
		adxl345_writeByte(BW_RATE, 0x17 ); // 0001 0111 (0x1A) - set to low power mode, bit 5 (was 0x0A, becomes 0x1A)
	}

	// activity
	if( (adxl345_irq_src >> 4) & 0x01) // if the act bit is set
	{
		Serial.println("Activity");

		// set the device back in measurement mode
		// as suggested on the datasheet, we put it in standby then in measurement mode
		//adxl345_writeByte(POWER_CTL_CFG, powerCTL & 11110011);
		//adxl345_writeByte(POWER_CTL, 0x04); // first standby
		//adxl345_writeByte(POWER_CTL_CFG, powerCTL & 11111011);
		//adxl345_writeByte(POWER_CTL, POWER_CTL_CFG); // then full measurement mode

		adxl345_writeByte(BW_RATE, 0x07 ); // 0000 0111 (0x0A) get back to full accuracy measurement (we will consume more power)
	}
	sei();
}

// ISR for timer5 events - generated every second
//	stuff that needs to run periodically goes here
ISR(TIMER5_COMPA_vect)
{
	uptime++; // increment every second

	flag_timer5_handler_execute = 1;

// construct which runs only once at power-up
	if(!flag_run_once)
	{
		flag_run_once = 1;

		//SPI voodoo - for some reason it is necessary for the ADXL345 to "work"
		SPI.beginTransaction(SPISettings(5000000, MSBFIRST, SPI_MODE3));
		adxl345_readByte(DEVID); // reads INT SRC to clear the act/inact bits
		adxl345_readByte(INT_SOURCE); // reads INT SRC to clear the act/inact bits
		adxl345_writeByte(BW_RATE, 0x07 );
		SPI.endTransaction();
	}
}

// catchall interrupt handler
ISR(BADISR_vect)
{
	Serial.println("!!! BADISR_vect !!!");
}

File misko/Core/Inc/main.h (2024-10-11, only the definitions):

#define Blue_User_Button_Pin GPIO_PIN_13
#define Blue_User_Button_GPIO_Port GPIOC
#define Blue_User_Button_EXTI_IRQn EXTI13_IRQn
#define LED_Red_Pin GPIO_PIN_0
#define LED_Red_GPIO_Port GPIOC
#define LED_Yellow_Pin GPIO_PIN_1
#define LED_Yellow_GPIO_Port GPIOC
#define GPS_WKUP_Pin GPIO_PIN_2
#define GPS_WKUP_GPIO_Port GPIOC
#define GPS_RESET_Pin GPIO_PIN_3
#define GPS_RESET_GPIO_Port GPIOC
#define ADC_VGPS_Pin GPIO_PIN_0
#define ADC_VGPS_GPIO_Port GPIOA
#define ROTARY_CH2_Pin GPIO_PIN_1
#define ROTARY_CH2_GPIO_Port GPIOA
#define SPI1_SD_CS_Pin GPIO_PIN_2
#define SPI1_SD_CS_GPIO_Port GPIOA
#define UART3_VCP_RX_Pin GPIO_PIN_3
#define UART3_VCP_RX_GPIO_Port GPIOA
#define UART3_VCP_TX_Pin GPIO_PIN_4
#define UART3_VCP_TX_GPIO_Port GPIOA
#define LED_Green_Pin GPIO_PIN_5
#define LED_Green_GPIO_Port GPIOA
#define SPI1_FRAM_CS_Pin GPIO_PIN_6
#define SPI1_FRAM_CS_GPIO_Port GPIOA
#define GPS_PWR_CTRL_Pin GPIO_PIN_4
#define GPS_PWR_CTRL_GPIO_Port GPIOC
#define ROTARY_CH1_Pin GPIO_PIN_2
#define ROTARY_CH1_GPIO_Port GPIOB
#define I2C2_SCL_Pin GPIO_PIN_10
#define I2C2_SCL_GPIO_Port GPIOB
#define CAN_STBY_Pin GPIO_PIN_12
#define CAN_STBY_GPIO_Port GPIOB
#define I2C2_SDA_Pin GPIO_PIN_13
#define I2C2_SDA_GPIO_Port GPIOB
#define UART1_TX_Pin GPIO_PIN_14
#define UART1_TX_GPIO_Port GPIOB
#define UART1_RX_Pin GPIO_PIN_15
#define UART1_RX_GPIO_Port GPIOB
#define CAN_RX_Pin GPIO_PIN_6
#define CAN_RX_GPIO_Port GPIOC
#define CAN_TX_Pin GPIO_PIN_7
#define CAN_TX_GPIO_Port GPIOC
#define Debug_Out_Pin GPIO_PIN_8
#define Debug_Out_GPIO_Port GPIOC
#define ADXL345_INT1_Pin GPIO_PIN_9
#define ADXL345_INT1_GPIO_Port GPIOC
#define ADXL345_INT1_EXTI_IRQn EXTI9_IRQn
#define SPI1_SCK_Pin GPIO_PIN_8
#define SPI1_SCK_GPIO_Port GPIOA
#define USB_FS_VBUS_Pin GPIO_PIN_9
#define USB_FS_VBUS_GPIO_Port GPIOA
#define USB_FS_DN_Pin GPIO_PIN_11
#define USB_FS_DN_GPIO_Port GPIOA
#define USB_FS_DP_Pin GPIO_PIN_12
#define USB_FS_DP_GPIO_Port GPIOA
#define SWDIO_Pin GPIO_PIN_13
#define SWDIO_GPIO_Port GPIOA
#define SWCLK_Pin GPIO_PIN_14
#define SWCLK_GPIO_Port GPIOA
#define JTDI_Pin GPIO_PIN_15
#define JTDI_GPIO_Port GPIOA
#define USB_FS_PWR_EN_Pin GPIO_PIN_10
#define USB_FS_PWR_EN_GPIO_Port GPIOC
#define SUPERCAP_DISCHARGE_Pin GPIO_PIN_11
#define SUPERCAP_DISCHARGE_GPIO_Port GPIOC
#define SD_CD_Pin GPIO_PIN_12
#define SD_CD_GPIO_Port GPIOC
#define USB_FS_OVCR_Pin GPIO_PIN_2
#define USB_FS_OVCR_GPIO_Port GPIOD
#define USB_FS_OVCR_EXTI_IRQn EXTI2_IRQn
#define SWO_Pin GPIO_PIN_3
#define SWO_GPIO_Port GPIOB
#define SPI1_MISO_Pin GPIO_PIN_4
#define SPI1_MISO_GPIO_Port GPIOB
#define SPI1_MOSI_Pin GPIO_PIN_5
#define SPI1_MOSI_GPIO_Port GPIOB
#define SPI1_ADXL345_CS_Pin GPIO_PIN_6
#define SPI1_ADXL345_CS_GPIO_Port GPIOB
#define SUPERCAP_EN_Pin GPIO_PIN_7
#define SUPERCAP_EN_GPIO_Port GPIOB
#define Anal_SW_CTRL_Pin GPIO_PIN_8
#define Anal_SW_CTRL_GPIO_Port GPIOB
#define SD_SPI_HANDLE hspi1
#define USE_ADXL345 1	// use the accelerometer
#define USE_FM25W256 1	// use the memory
#define USE_SD 1	// use the SD card
#define USE_ORG1510MK4 1 // use the GPS module
#define USE_LOGGER 1	// use the logger
#define OFF 0	// global device states
#define ON 1
#define ADC_CHANNELS 4	// how many ADC channels are we using
#define ADC_MEASURE_ITERATIONS 8 // average over one second (time-base is timer1 on a 125ms)

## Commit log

2016-07-21 created rough tactical tailor universal hardcase 50 autocad drawing with dimensional annotations
    more info on the case under http://www.tacticaltailor.com/universalhardcase50.aspx
    [universal hardcase 50.dwg]
2016-07-21 a crude drawing of lithium polymer batteries used
    the exact battery is this:
    http://www.alpha-crucis.com/en/batteries/2396-polymer-lithium-ion-battery-37v-6ah-3700386684845.html
    JSP-PH connectors are these:
    http://www.alpha-crucis.com/en/connectors-en/3344-jst-vertical-connector-3700386686139.html
    http://www.alpha-crucis.com/en/connectors-en/3343-jst-right-angle-connector-3700386686122.html
    cable mounted:
    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
    [LiIon battery.dwg]
2016-07-21 a crude drawing of the tactical tailor 50 hardcase
    the case can be found here:
    http://www.tacticaltailor.com/universalhardcase50.aspx
    [universal hardcase 50.dwg]
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2016-07-23 sort of working prototype code there are issues with it (no order of importance): - lack of comments - ugly code, not optimized at all - SD card writing burns the card on write (often onto the same b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
    [misko-prototype.ino, pin_definitions.h, pin_modes.h]
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2016-07-24 added AVR186 - Best Practices for the PCB layout of Oscillators.pdf
2016-07-24 added lots of FIXMEs for not implemented / known issues
    [pin_modes.h]
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2016-07-26 corrected the case name from 50 to 75 ( i named it wrongly)
    [universal hardcase 75.dwg]
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2016-07-26 reverted back to previous version, will branch for button testing
    [misko-prototype.ino]
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2016-07-30 -added printout of button press to verify correct hardware debouncing circuit operation
    [misko-prototype.ino]
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2016-07-30 -corrected eeprom_timer() function declaration
    [functions.h]
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2016-08-01 - replaced digitalWrite(lcd_mosfet_gate_pin, HIGH) with OLED.Write_IIC_Command(0xAF) - replaced Serial.println() of button press with corresponding OLED.Char_F6x8() - replaced digitalWrite(lcd_mosfet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
    [functions.h]
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2016-08-03 - added the picture loop
    now hellow world gets printed out reliably, as it seems, across reboots
    [misko-prototype.ino]
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2016-08-04 - produced a working example of hello world - turned off sd card init, since it seems to crash the graphics library - the picture loop still renders the NMEA input non-working, since the picture loop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
    [functions.h, misko-prototype.ino]
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2016-08-07 - corrected key definitions to be according to menu2l
    [setup.h]
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2016-08-08 - corrected eeprom_set() and eeprom_get() function definitions (had wrong names)
    [functions.h]
2016-08-08 - corrected a typo
    [functions.h]
2016-08-08 - minor tweaks (typo fixes, correction of dumb errors)
    [functions.h, global_variables.h]
2016-08-08 - corrected merge issues
    [functions.h, misko-prototype.ino, setup.h]
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2016-08-09 - in U8GLIB_SH1106_128X64_2X constructor call replaced a0 numerical with #define'd pin name
    [global_variables.h]
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2016-08-12 - changed to unique names for DO_NOT_USE_pin_x to avoid compiler warnings
    [pin_definitions.h]
2016-08-12 - replaced unsigned int with uint8_t - decreased SD_BUFFERSIZE to 4096 in order to have some spare memory left for coding
    [global_variables.h]
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2016-08-17 - defined bat_A_pin and bat_B_pin (not yet used) - added sleep_indicator_pin - corrected UART descriptions and added pin numbers - added sim800l_mosfet_gate_pin
    [pin_definitions.h]
2016-08-17 - added Serial2.begin() for SIM800L - modified attachInterrupt() for ADXL345 (replaced numeric 2 with #define'd interrupt_adxl345_int1_pin)
    [setup.h]
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2016-08-18 - corrected bat_B_pin (typo)
    [pin_definitions.h]
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2016-08-20 - activated poor mans debugging for some weird SPI interference issue
    [functions.h]
2016-08-20 - corrected function comments - implemented fn_get_batt_charge_status() callback - implemneted fn_get_power_good_status() callback - modified display to include MCP73871 charge/power status
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2016-08-20 - added bat_a_pct[9] = "batAxxx%" - corrected AREF to 4.25
    [global_variables.h]
2016-08-20 - replaced values for power settings of the oled and bluetooth with numerical values for auto (was 'a', now it is a number)
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2016-08-22 - added missing scheduler_run_count++; to ISR(TIMER5_COMPA_vect)
    [misko-prototype.ino]
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2016-08-22 - finally implemented gps_adjust_log_freq() correctly
    [functions.h]
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2016-08-26 - put debug printouts into #if BUFFER_DEBUG_PRINT clauses - corrected len and rest casting to give proper results
    [functions.h]
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2016-08-29 - corrected a bug in the display of the timezone; now "+" is displayed for positive offset and "-" for negative.
    [functions.h]
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2016-08-31 - further rework of the schematic
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2016-08-31 - added LTC3525-3.3 - corrected wrong connection two MCP73871 resistors (two outgoing from THERM port)
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2016-09-01 - softwareserial port issues - SPI_OLED_reset_pin and SPI_OLED_a0_pin will need to be rerouted in the schematic
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2016-09-01 - minor corrections across the schematic
2016-09-02 - corrected getCheckSum - stringlenght was off - added #ifdef-ed log freq settings for GPS_MTK3339_CHIP and GPS_EM406A_CHIP
    [functions.h]
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2016-09-05 - corrections in schematic element names/values - added USB to Serial page (FTD230)
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2016-09-05 - added ideal diode + supercap to GPS power supply - corrected few element names/values
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2016-09-07 - corrected adxl345 int1 pin, - corrected other minor things
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2016-09-09 - corrected analog switch schematic
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2016-09-11 - work on temerature function - DOES NOT WORK YET PROPERLY (is not displayed; the value is ok, though)
    [functions.h]
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2016-09-12 - removed SPI serial resistors - moved ICSP header to top of board - routed PDI/PDO to ICSP header - rerouted Vcc, routed it to ICSP header - routed reset line to ICSP header - added comments to sele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
2016-09-12 - corrected a few ground issues with thermal pads, tested traces with ground plane enabled
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2016-09-18 - corrected reset route towards switch (went to wrong via)
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2016-09-21 - corrected GPS module orientation - moved pullup from GPS CTS pin (7) from Vcc to 1V8 - added level shifting transistor circuit to wakeup line, which is on a 1V8 logic level
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2016-09-27 - switched project to AtmelStudio7, the arduino ide will no longer be used actively
    [adxl345.h, functions.h, global_variables.h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]
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2016-10-16 - removed DIP (and pullup resistor) from GPIO4 (pin 22) on bluetooth module (was a DIP for factory reset: not needed since it can be triggered by tweezers) - renumbered items - new BOM
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2016-10-31 - added GNRMC & GNGGA examples - removed GPS TOW and WK parsers - corrected fix LED power control (it became inverse logic) - corrected checks for RMC and GGA sentence (from GP to GN)
2016-10-31 - corrected GPS power handling - serial redirection is still problematic
2016-10-31 - corrected SD card LED power handing (it became inverse logic)
    [functions.h]
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2016-11-09 - rerouted ADXL345 INT1 and SD card detect lines. originally the ADXL345 was on PB6 (which could only do PCINTs and had to share them with softwareserial), the SD card detect pin was on PE7 (an hardw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
2016-11-13 - added a FIXME
    [setup.h]
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2016-11-23 - modified handle_bluetooth_button(), fn_cb_bluetooth_power_setting(), fn_cb_serial_setting() to use feram and not eeprom - added fn_cb_gps_fix_indicator() for indication of the kind of fix we have -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
    [functions.h]
2016-11-23 - implemented fn_cb_gps_fix_indicator() - returns a string indicating the nature of the gps position fix
    [functions.h]
2016-11-23 - resolved gps_satellites_in_view[] = "" issue
    [global_variables.h]
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2017-04-13 3-deck board consisting of : deck 1: lower side: power supply, upper side: cpu, spi bus, deck 2: lower side: sim800 + holder, upper side: bluetooth module, gps supercap+circuit deck3: lower side: mis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
    [misko.brd, misko_3_board.brd, misko_3_board.sch]
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2017-04-14 - further progress on the 3-deck board, top portion needs rework due to final oled module
    [misko_3_board.brd, misko_3_board.sch]
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2017-04-15 - correction of int7 pin (-> adxl345 int1)
    [misko_3_board.brd, misko_3_board.sch]
2017-04-15 - replaced JST-PH with through-hole variant
    [misko_3_board.brd, misko_3_board.sch]
2017-04-15 - sized up deck1 holes to 3mm dia, adjusted ground for TH JST socket
    [misko_3_board.brd]
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2017-04-16 - further progress on top deck board (oled space marked in tplace), joystick added, missing JTAG header and led/switch header
    [misko_3_board.brd, misko_3_board.sch]
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2017-04-17 - final steps on 3-deck boards: copper mask, ground vias, 4th board for led/switches (to be mounted on lid)
    [misko_3_board.brd, misko_3_board.sch]
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2017-04-17 - corrections to the model on base of an example print
    [battery holder.dwg, battery holder_1.stl, battery holder_2.stl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]
2017-04-17 - switched to 6x6 SPST-NO switches, corrected a minor ammount of ratlines
    [misko_3_board.brd, misko_3_board.sch]
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2017-04-20 - added DS1394U-33+ RTC SPI Module, corrected a few traces
    [misko_3_board.brd, misko_3_board.sch]
2017-04-20 - added DS13944U-33+RTC SPI module.pdf and its oscillator LFXTAL016178R 32.768kHz crystal.pdf
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2017-05-01 - checked against prototype schematic, minor error corrections
    [misko_3_board.brd, misko_3_board.sch]
2017-05-06 - added missing mounting holes
2017-05-06 - added supervisor circuit to monitor VGPS and assert power on once conditions are met (functions as an AND gate: GPS_POWER_CTL_PIN AND min. 3V03 on VGPS will power on the GPS receiver)
    [misko_3_board.brd, misko_3_board.sch]
2017-05-06 - corrected ground pads so that they get connected to pcb ground on ratnesting them in eagle
2017-05-07 - corrected names and place layers for top and bottom
    [misko_3_board.brd, misko_3_board.sch]
2017-05-07 - corrected supercap orientation - routed remaining airwires - disapproved any error for last sanity check
    [misko_3_board.brd, misko_3_board.sch]
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2017-05-08 - finished board & schematic, corrected BOM
    [misko_3_board.brd, misko_3_board.sch]
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2017-05-13 - corrected too big spatial dimensions (took 1mm off), rerouted what needed to be rerouted, ERC & DRC are error free
    [misko_3_board.brd]
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2017-05-21 - implemented capacitor bank for support of solar panels (see adafruits solar charger)
    [misko_3_board.brd, misko_3_board.sch]
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2017-05-25 - corrected for larger holes on 1.27mm connectors - moved fiducials around - rerouted a few traces around the 1.27mm connectors - added milling around mini usb socket
    [misko_3_board.brd, misko_3_board.sch]
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2017-05-26 - corrected wrong layout for ltc4425, updated gerber files
    [misko_3_board.GBL, misko_3_board.GBO, misko_3_board.GBP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]
2017-05-26 - corrected ltc4425 footprint
2017-05-27 - corrected position of liion bypass cap
    [misko_3_board.GBL, misko_3_board.GBO, misko_3_board.GBP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]
2017-05-28 - corrected usb connector slot representation in physical footprint
2017-05-28 - corrected a few widths, buzzer holes
    [misko_3_board.brd, misko_3_board.sch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]
2017-05-28 - corrected milling pattern
    [misko_3_board.brd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]
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2017-06-08 - bill of materials in csv format - unified voltage divider resistors - corrected capacitor value 100nF -> 0.1µF
    [misko_3_board.brd, misko_3_board.sch, misko_3_board.xlsx]
2017-06-11 - replaced LTC4425's Vmid capacitor divider by resistors -
    [misko_3_board.GBL, misko_3_board.GBO, misko_3_board.GBP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]
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2017-06-11 - replaced TH reset switch with smaller SMD part
    [misko_3_board.GBL, misko_3_board.GBO, misko_3_board.GBP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]
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2017-06-14 - corrected resisitor divider for LTC4425 - R60/61 now connect to Vgps (instead of Vcc)
    [misko_3_board.brd, misko_3_board.sch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]
2017-06-14 - removed power fail functionality from LTC4425 since it is not needed at all
    [misko_3_board.brd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]
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2017-06-17 - cleaner up timer5 ISR so that it is as short as possible; the ISR now sets flags only, which in turn are monitored and acted upon in loop()
    [misko-prototype.ino]
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2017-06-18 - modified ok button callbacks in such a way that on "ok" press the cursor returns to the menu item instead of the topmost menu item in the list - replaced incorrect FERAM_GPS_LAST_GOOD_POSITION with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
    [functions.h]
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2017-08-01 - replaces USB mini D socket with SMT version, deleted old datasheet/eagle library
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2017-08-02 - corrected antenna keep-out area
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2017-08-04 - single board redrawn, pin mapping updated in pin_definitions.h - ERC&DRC to be checked next
    [misko_1_board.brd, misko_1_board.sch]
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2017-08-14 - replaced SN74LVC2G14DBVT Schmitt Trigger, inverting.pdf with MAX6818 CMOS Switch debouncer.lbr, added/removed respective datasheets
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2017-08-17 - changed tplace misplacements of lines on solder pads, corrected holes for proper drill diameter
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2017-08-30 - corrected values for L1
    [misko_1_board.brd, misko_1_board.sch]
2017-08-30 - corrected name placement for R39 and R33
    [misko_1_board.brd]
2017-08-30 - corrected name placement for R12 and R13
    [misko_1_board.brd]
2017-08-30 - corrected placement of C34 (was on wrong side of board)
    [misko_1_board.brd]
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2017-08-31 - moved R12, R13 and C42 to have more room for the battery JST-PH connector
    [misko_1_board.brd]
2017-08-31 - rotated JST-PH connector so that it is placed in accordance with the battery polarity on its JST connector (was reversed before the change)
    [misko_1_board.brd, misko_1_board.sch]
2017-08-31 - corrected name labeling of 5V0, VUSB, LiPo connectors at top right board edge
    [misko_1_board.brd]
2017-09-01 - moved 13 slightly to have more room for the JST-PH connector
    [misko_1_board.brd]
2017-09-08 - grounded MAX6818 !EN! pin to work properly: now key release is high, key press is low on the joystick and buttons
    [misko_1_board.brd, misko_1_board.sch]
2017-09-08 - redraw of MAX6818 CMOS Switch debouncer.lbr and board layout; the pattern was too narrow
    [misko_1_board.brd, misko_1_board.sch]
2017-09-08 - corrected missing name and value text in MAX6818 CMOS Switch debouncer.lbr, updated board layout
    [misko_1_board.brd, misko_1_board.sch]
2017-09-08 - corrected joystick signal routing of down and right signal around holes; they had a short to ground in the rev2. layout
    [misko_1_board.brd]
2017-09-08 - added another bypass cap to the TPS63031 - Buck Boost Voltage Regulator, as per datasheet
    [misko_1_board.brd, misko_1_board.sch]
2017-09-11 - updated micro joystick.lbr (removed tplace from pads) and LFXTAL016178R 32.768kHz crystal.lbr (added pin1-alike mark to distinguish fron from back)
    [misko_1_board.brd, misko_1_board.sch]
2017-09-11 - updated micro joystick.lbr so that tplace does not go over pads, lengthened the tplace footprint and moved a bit down towards the cpu (it stood over the board edge a little bit)
    [misko_1_board.brd, misko_1_board.sch]
2017-09-11 - enlarged diameter of through holes for wire-connected nets (they were too thin to solder)
    [misko_1_board.brd]
2017-09-15 - corrected JTAG 1.27mm 10pin header.lbr; pinout was pairwise swapped - corrected board layout to accommodate new JTAG header orientation
    [misko_1_board.brd, misko_1_board.sch]
2017-09-15 - added zener protection diodes to wifi, bluetooth modules and 5v0 input
    [misko_1_board.brd, misko_1_board.sch]
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2017-09-16 - specified value for 3V3 protection diode (is in reality a 3V8 diode)
    [misko_1_board.brd, misko_1_board.sch]
2017-09-23 - corrected values for oscillator load capacitors
    [misko_1_board.brd, misko_1_board.sch]
2017-09-23 - named FTDI RX/TX LEDs properly in schematic and on board layout (tplace)
    [misko_1_board.brd, misko_1_board.sch]
2017-09-23 - added pulldown (R23) to GPS_POWER_CTL_PIN so that the receiver is turned off when micro controller resets
    [misko_1_board.brd, misko_1_board.sch]
2017-09-27 - small c program to test the new hardware for correct operation on it prod code shall be developed
    [main.c]
2017-09-27 - added RX/TX text on tplace near serial comm. vias shortly before FTDI IC
    [misko_1_board.brd]
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2017-09-29 - added crude driver for DS1394U-33+ RTC clock - corrected FRAM SS name to SPI_SS_FRAM_pin
    [main.c]
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2017-10-01 - in schematic placed Vina bypass cap. on TPS63031 closer to Vina pin to make placement clearer
    [misko_1_board.sch]
2017-10-01 - corrected EN pulldown resistor value to 10k
    [misko_1_board.brd]
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2017-10-01 - some more refinements on the GPS lib and on the DRC (now there is a space of 0.5mm between board edge and copper)
    [misko_1_board.brd, misko_1_board.sch]
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2017-10-01 - DRC on last changes is now error-free
    [misko_1_board.brd]
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2017-12-24 - corrected device name of TPS63031
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2017-12-31 - added SP3012 TVS Diode Array.lbr into schematic and routed element to USB port
    [misko_1_board.brd, misko_1_board.sch]
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2018-01-05 - corrected supercap position
    [misko_1_board.brd, misko_1_board.sch]
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2022-01-15 - more submodule issues
    [adxl345.c, adxl345.h, main.c]
2022-01-16 general: - added gpio macros - sort of resolved UART submodule conflict
    ATMega2561.c:
    - added peripherals config (atm only USART0)
    - added SPI bus config
    - added interrupt config (atm only INT7 for ADXL345)
    spi.c/.h:
    - wrote low level SPI communication driver
    adxl345.c/.h:
    - wrote device driver
    misko.c/.h:
    - minor struct changes
    main.c:
    - added uart putstring for fancy debugging
    [adxl345.c, adxl345.h, main.c]
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2022-01-27 - added two missing files (uart and gpio code/headers) to base project
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2022-02-27 eagle libraries: added devices, modified existing ones to be more correct in terms of pin directions, layers, dimensions, etc.
    eagle design:
    added nucleo expansion board & populated SPI, UART, SPI device pins
    - added ADXL345 Accelerometer driver
    - added FM25W256 FERAM driver (standin for future MRAM module)
    - added code in main() to test above drivers
    [misko_nucleo.sch]
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2024-01-16 - renamed a few pins - minor correction to start string
    [main.c, main.h, misko.ioc]
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2024-01-16 - added missing project files to git - created spi.c/.h & adxl345.c/.h for driver development
    [adxl345.h, main.c]
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2024-01-17 - corrected a SPI SCK issue with sck being low on idle (activated a pullup)
    in adxl345.c:
    - #define-d the SPI timeout (instead of magic number)
    [adxl345.c, misko.ioc]
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2024-01-28 - reverted ffconf.h to original (except code page change) - commented out file read code
    [main.c]
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2024-01-30 - moved gps components into misko nucleo schematic - corrected component library issues
    [misko_nucleo.brd, misko_nucleo.sch]
2024-01-30 - corrected net names in modules
    [misko_nucleo.brd, misko_nucleo.sch]
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2024-01-30 - added/coded and routed ORG1510-MK4 GPS module reset and LTC4425 SuperCap Charger enable pins
    [misko_nucleo.brd, misko_nucleo.sch]
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2024-02-03 in main.h: - corrected ADC_MEASURE_ITERATIONS to 8 to really be 1s
    in misko.ioc:
    - pulled up all UART RX & TX GPIOs
    - corrected GPS reset GPIO to be pulled high
    - set DMA channel 3 (GPS/UART1 RX) to circular DMA
    - misc hacks to develop org1510mk4 power saving state changes
    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
    [main.c, main.h, misko.ioc]
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2024-02-04 in org1510mk4.c: - improved reset mode handling (tested with GPRMC every 5s -> reset)
    [main.c, org1510mk4.c]
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2024-02-05 - added a tiny bit of error checking to Write()
    [org1510mk4.c]
2024-02-05 in misko.ioc, main.c & others: - switched UART1 TX from DMA to interrupt, since it will be an on-off event and not constant a stream like RX is
    in org1510mk4.c:
    - implemented _init() for reset
    - modified _Write() to use HAL_UART_Transmit_IT() instead of HAL_UART_Transmit_DMA()
    [main.c, misko.ioc, org1510mk4.c]
2024-02-06 in org1510mk4.c: - improved the reset power mode slightly by adding delays and shutting the NMEA burst up before init commands are issued
    [main.c, org1510mk4.c]
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2024-02-11 in org1510mk4.c: - corrected ring buffer fill function, now the ringbuffer is getting filled correctly
    [org1510mk4.c]
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2024-02-14 in org1510mk4.c: - made code for circular dma rx buffer handling more readable - added FIXMEs to blocking parts of Power()
    [org1510mk4.c]
2024-02-14 in org1510mk4.c: - fixed compiler warnings around lwrb_sz_t rest, extra and len variables
    [org1510mk4.c]
2024-02-14 in misko.ioc: - narrowed down priority groups from 4/0 bits to 3/1
    - fixed hard fault (was incorrect usage of lwrb read functions
    - added FIXMEs
    - extended logic for parsing a little bit
    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
    [misko.ioc, org1510mk4.c]
2024-02-14 in org1510mk4.c: - fixed bug where some NMEA sentences would appear twice
    [org1510mk4.c]
2024-02-14 in org1510mk4.c: - implemented absolutely hideous date/time/fix parsing
    [org1510mk4.c]
2024-02-15 in org1510mk4.c: - fixed a gga gps fix parsing issue - converted xda-derived time to a string in hhmmss format
    [org1510mk4.c]
2024-02-16 in stm32h5xx_it.c: - in timer1's ISR added check for GPS fix type and have the green LED be blinking/on/off accordingly
    - in _Parse() moved 1st buffering into void load_into_1st_buffer(lwrb_t *rb, const uint16_t high_pos)
    in _Parse() moved 2nd buffering into uint8_t load_into_2nd_buffer(lwrb_t *rb, uint8_t *temp)
    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
    [org1510mk4.c]
2024-02-16 in org1510mk4.c: - replaced standard tokenizer with some other function: char* strtok_f(char *s, char delim) and fixed GGA parsing issues - renamed ringbuffer functions for loading 1nd buffer from DM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
    [org1510mk4.c]
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2024-02-18 in org1510mk4.c: - corrected few issues with power state changes
    general:
    changed some fixme comments
    [main.c, org1510mk4.c, sd.c]
2024-02-18 in org1510mk4.c/.h: - implemented RMC parsing but ultimately deactivated that code - fixed GSV hardfault issue and improved parsing - restructured parsing functions to work with sentence type referen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
    [org1510mk4.c]
2024-02-18 in org1510mk4.c/.h: - fixed GSA tokenizer crap bug when 13th satellite appeared for some reason - prepared GLANOSS parsing
    [org1510mk4.c]
2024-02-19 in org1510mk4.c: - fixed bug in GSV code
    [org1510mk4.c]
2024-02-19 in org1510mk4.c/.h: - in gsa_t replaced 12x uint8_t sv01 with spacevehicle_t *sv[12] - removed public gpgsa, glgsa, gpgsv, glgsv from ORG1510 struct - removed _gpgsa, _glgsa - implemented static spac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
    [org1510mk4.c]
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2024-02-24 in main.c: - added key combo for reset
    - corrected GLL parsing
    - added crude code to discharge the supercap
    - cleaned up GPS module device config in init()
    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
    [main.c, nmea_objects.h, org1510mk4.c]
2024-02-25 addition to last commit: missed some changes
    [org1510mk4.c]
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2024-02-29 in org1510mk4.c/.h: - fixed flapping values for GSVs after id 4 (msgs 2 and 3) - fixed zeroing of alm and eph fields if a PRN is/becomes zero
    - added flag setting of once per 10s for almanac/ephemeris query
    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
    [org1510mk4.c]
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2024-03-02 added timehelper_t: an objwect which sets either RTC or GPS time according to what has the more correct time
    in org1510mk4.c/.h & main.c:
    - implemented the timehelper
    [main.c, org1510mk4.c, timehelper.c]
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2024-03-05 in org1510mk4.c/.h: - moved date & time into time_t and date_t structs - adapted NMEA parsers to use said structs - corrected preprocessor defines
    in timehelper.c:
    - simplified date & time set to use above structs
    [main.c, nmea_objects.h, org1510mk4.c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]
2024-09-15 in sch & brd: - changed hierarchical module names so that board components have shorter names (GPS subsystem stuff) - added CAN infra. components to sch
    [misko_nucleo.brd, misko_nucleo.sch]
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2024-09-15 - few code corrections due to upgrade
    [nmea_objects.h, org1510mk4.c, timehelper.c]
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2024-10-12 - corrected timer1 to have a 125ms interrupt period (measured) vs. calculated
    [main.c, misko.ioc]
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2024-10-25 - corrected BOM items - renamed BOM
    [misko bom.xlsx, misko_nucleo BOM.xlsx]
2024-11-14 minor corrections for rev.3 board: - corrected UART1 lines towards board - added debug and attach launch configs - adapted code to match rev.3 board
    - corrected BOM items
    - renamed BOM
    [misko bom.xlsx, misko_nucleo BOM.xlsx, misko_nucleo.brd]
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

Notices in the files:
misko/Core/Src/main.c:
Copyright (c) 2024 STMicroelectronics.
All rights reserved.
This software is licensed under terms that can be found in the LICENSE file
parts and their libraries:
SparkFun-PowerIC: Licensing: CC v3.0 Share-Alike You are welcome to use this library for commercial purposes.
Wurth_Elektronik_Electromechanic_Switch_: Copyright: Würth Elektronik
